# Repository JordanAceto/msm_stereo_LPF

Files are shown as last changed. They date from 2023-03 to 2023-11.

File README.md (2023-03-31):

## Stereo 24dB/octave Lowpass Filter for Matt

### Features:
- All analog audio path
- Minimoog style resonant lowpass filters
- Subtle adjustable compression
- FET based overdrive
- Envelope follower with adjustable attack time
- Dual digital LFO with flexible routing and syncing options
- Sum and Difference outputs for interesting Mono combinations of the two filters

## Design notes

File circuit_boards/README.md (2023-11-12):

## PCB design and documentation files

### The system is made up of several printed circuit boards
- `compression_and_distortion` has an NE570 compressor and FET distortion circuit
- `lowpass_filters` contains the voltage controlled lowpass filters
- `envelope_follower` is an analog envelope follower
- `LFO_and_PS` contains a regulated bipolar DC power supply and digital LFO

### Each circuit board has a subdirectory with
- KiCad 7 project files with KiCad
- Documentation needed to build the board in `docs`

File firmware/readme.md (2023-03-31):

# STM32L031 Dual Low Frequency Oscillator

---

### Features:

- Rate and Depth controls per LFO, all ranging from 0v to +3.3v:
- LFO A has TRIANGLE, SQUARE, and SAMPLE & HOLD waveforms
- LFO B is always TRIANGLE wave
- LFO A can be switched to FAST mode, which pushes the frequency into the audio range for scifi FX

---

### LFO Modes:

A 3-position rotary switch determines how LFO A and LFO B work together.

#### NORM Mode
LFO A and LFO B are completely independent. Below is one example setting, with LFO A in blue set relatively slow and LFO B at a faster rate in purple.

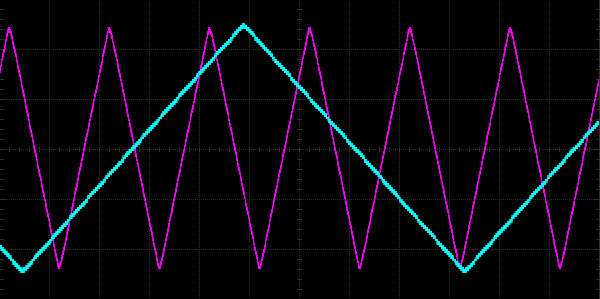
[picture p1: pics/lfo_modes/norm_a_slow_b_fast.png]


#### SYNC TO A Mode
Forces both A and B sides to use only the output of LFO A. The B side may be inverted relative to the A side. 

This mode is good for straightforward stereo panning effects. The RATE B control has no effect in this mode.

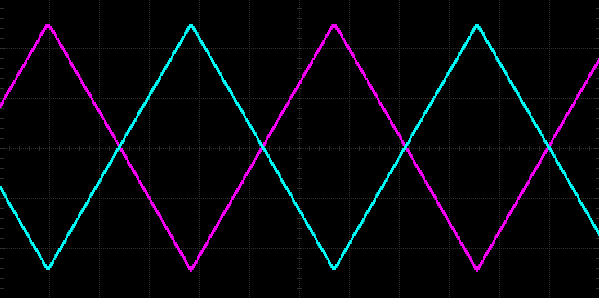
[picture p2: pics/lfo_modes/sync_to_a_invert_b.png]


#### ADD Mode
The most complex. The contributions of LFO A and LFO B are summed together.

In this mode the DEPTH A knob controls how much of LFO A is applied to both filter A and filter B. Likewise the DEPTH B knob controls how much of LFO B is applied to both filters.

The INVERT B switch inverts the contribution of LFO B going to filter B.

This allows us to create a variety of complex modulation schemes like shown below. In all images the contribution going to filter A is shown in blue and filter B modulation is purple.

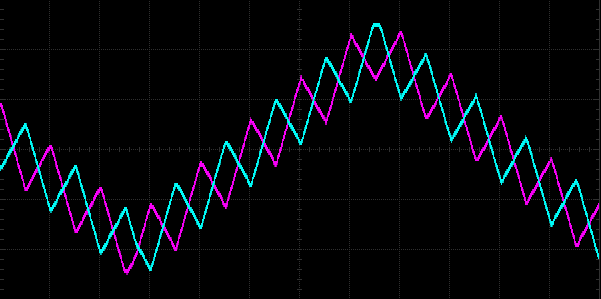
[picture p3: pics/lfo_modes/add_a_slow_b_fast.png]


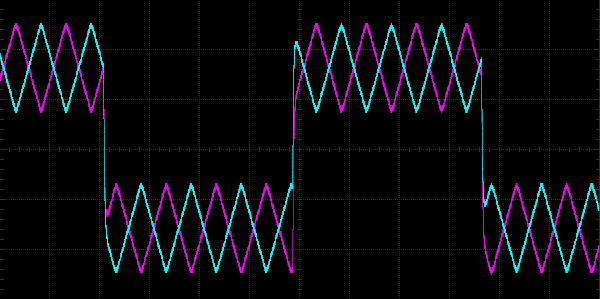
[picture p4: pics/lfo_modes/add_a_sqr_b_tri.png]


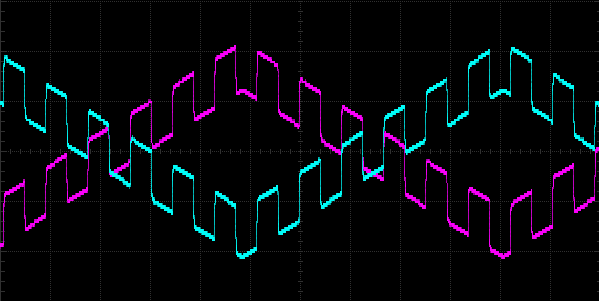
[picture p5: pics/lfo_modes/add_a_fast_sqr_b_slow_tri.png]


---

### Prerequisites for building and flashing the project:
- [arm-none-eabi toolchain](https://developer.arm.com/tools-and-software/open-source-software/developer-tools/gnu-toolchain/gnu-rm/downloads)
- [GNU make](https://www.gnu.org/software/make/)
- [st-link utility](https://www.st.com/en/development-tools/stsw-link004.html)
- A physical st-link device. I use an old [Nucleo board](https://www.st.com/en/evaluation-tools/stm32-nucleo-boards.html).
- If you have a different preferred method of flashing STM32 chips (openocd, etc) then feel free to go wild.

### To build the project:
- `$ make`

### To flash an STM32 chip connected to an st-link programmer via the SWD header:
- `$ make write`

---

### Firmware directory organization:
- `third_party` contains the STM32 supplied CMSIS header-only files, assembly startup routine, and linker script.
- `BSP` is a very basic "Board Support Package", this module initializes and modifies the various stm32 peripherals used by the system.
- `lib` contains user library files.
- `src` contains the main application files.
- `utils` contains non-c language utility source files such as a python lookup table generating script.
- `bin` is the destination for output files generated by the build process.

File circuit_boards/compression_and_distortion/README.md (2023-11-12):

# compression_and_distortion

## compressor_distortion

PCB front
PCB back

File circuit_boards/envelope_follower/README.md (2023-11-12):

# envelope_follower

## envelope_follower

PCB front
PCB back

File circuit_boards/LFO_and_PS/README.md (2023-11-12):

# LFO_and_PS

## lfo_and_power_supply

PCB front
PCB back

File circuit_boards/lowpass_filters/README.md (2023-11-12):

# lowpass_filters

## filter_board

PCB front
PCB back

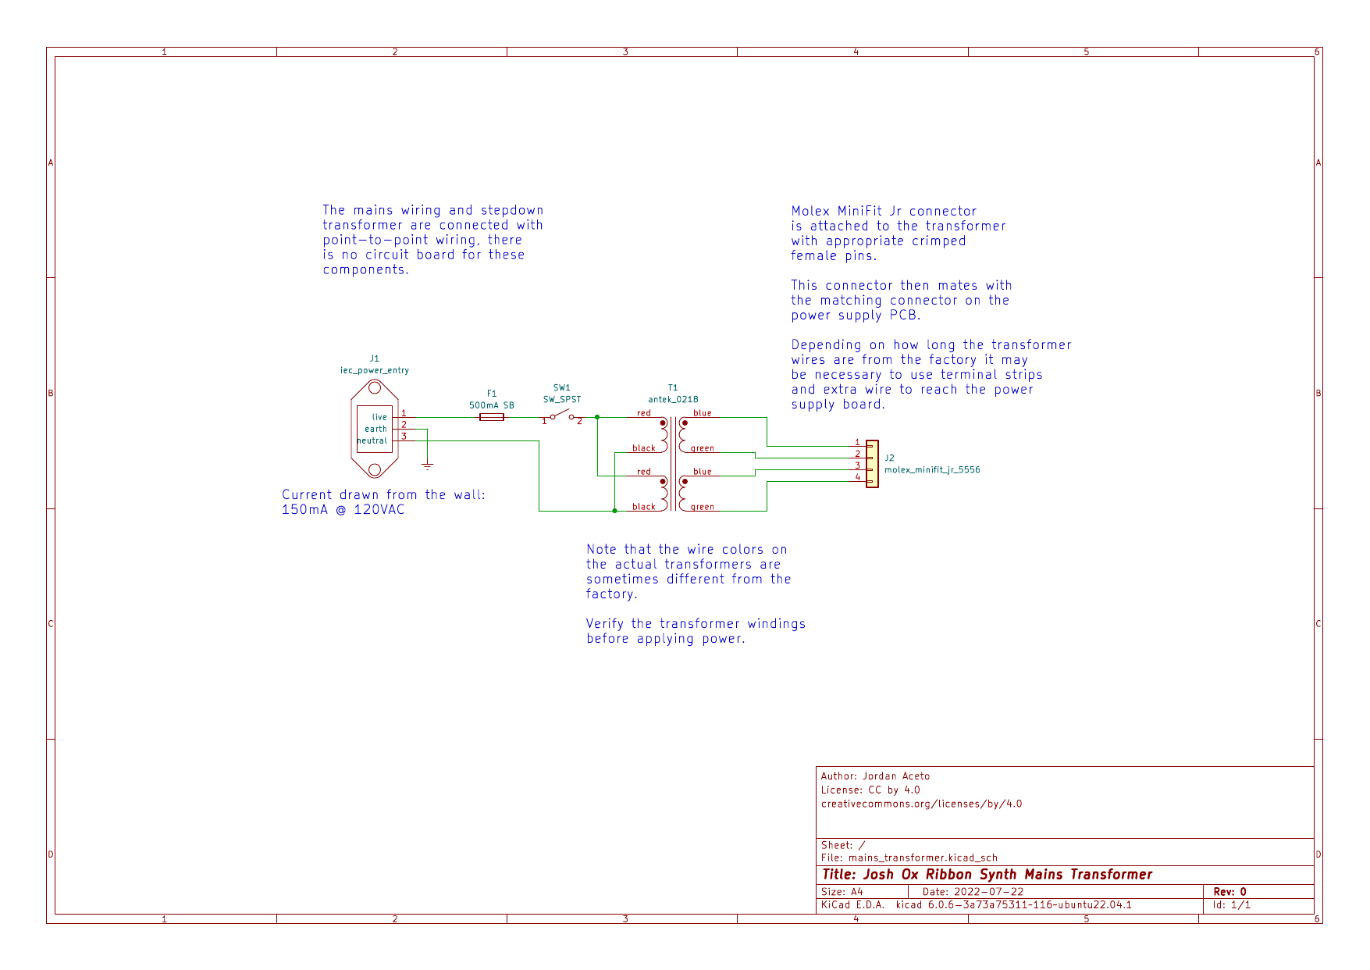
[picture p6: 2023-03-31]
circuit_boards/mains_transformer/main_transformer.png

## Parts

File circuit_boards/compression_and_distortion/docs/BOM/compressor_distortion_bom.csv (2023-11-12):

# | Reference | Qty | Value | Footprint | DNP
1 | C1, C2, C3, C4, C8, C9, C10, C11, C21, C22, C23, C24 | 12 | 1u | Capacitor_THT:C_Rect_L7.2mm_W5.5mm_P5.00mm_FKS2_FKP2_MKS2_MKP2
2 | C5, C12 | 2 | 2u2 | Capacitor_THT:CP_Radial_D6.3mm_P2.50mm
3 | C6, C13, C16, C19, C27, C28 | 6 | 10u | Capacitor_THT:CP_Radial_D6.3mm_P2.50mm
4 | C7, C14 | 2 | 220p | Capacitor_SMD:C_0805_2012Metric
5 | C15, C17, C18, C20 | 4 | 100n | Capacitor_THT:C_Rect_L7.2mm_W2.5mm_P5.00mm_FKS2_FKP2_MKS2_MKP2
6 | C25, C26 | 2 | 100p | Capacitor_SMD:C_0805_2012Metric
7 | C29, C30, C31, C32, C33, C34, C35, C36, C37, C38, C39 | 11 | 100n | Capacitor_SMD:C_0805_2012Metric
8 | D1, D2 | 2 | red | LED_SMD:LED_0805_2012Metric
9 | D3, D4 | 2 | red_green | LED_THT:LED_D5.0mm
10 | J1 | 1 | dry_in | Connector_Molex:Molex_KK-254_AE-6410-04A_1x04_P2.54mm_Vertical
11 | J2 | 1 | vcf_board_send_receive | Connector_Molex:Molex_KK-254_AE-6410-08A_1x08_P2.54mm_Vertical
12 | J3 | 1 | final_out | Connector_Molex:Molex_KK-254_AE-6410-07A_1x07_P2.54mm_Vertical
13 | J4 | 1 | power_entry | Connector_IDC:IDC-Header_2x05_P2.54mm_Vertical
14 | Q1, Q3 | 2 | BS170 | Package_TO_SOT_THT:TO-92_Wide
15 | Q2, Q4 | 2 | BF245A | Package_TO_SOT_THT:TO-92_Wide
16 | R1, R2 | 2 | 470k | Resistor_SMD:R_0805_2012Metric
17 | R3, R9, R20, R28 | 4 | 10k | Resistor_SMD:R_0805_2012Metric
18 | R4, R10 | 2 | 3k3 | Resistor_SMD:R_0805_2012Metric
19 | R5, R6, R11, R12 | 4 | 47k | Resistor_SMD:R_0805_2012Metric
20 | R7, R13 | 2 | 2M2 | Resistor_SMD:R_0805_2012Metric
21 | R8, R14 | 2 | 22k | Resistor_SMD:R_0805_2012Metric
22 | R15, R21, R23, R29 | 4 | 1k | Resistor_SMD:R_0805_2012Metric
23 | R16, R17, R24, R25 | 4 | 1M | Resistor_SMD:R_0805_2012Metric
24 | R18, R26 | 2 | 4k7 | Resistor_SMD:R_0805_2012Metric
25 | R19, R27 | 2 | 2k | Resistor_SMD:R_0805_2012Metric
26 | R22, R30, R31, R32, R33, R34, R35, R36, R37, R38, R39, R40, R41, R42, R43 | 15 | 100k | Resistor_SMD:R_0805_2012Metric
27 | R44, R45 | 2 | 100 | Resistor_SMD:R_0805_2012Metric
28 | RV1, RV2, RV3 | 3 | 100k | Potentiometer_THT:Potentiometer_Alpha_RD902F-40-00D_Dual_Vertical
29 | RV4, RV5 | 2 | 50k | Potentiometer_THT:Potentiometer_Bourns_3296W_Vertical
30 | SW1 | 1 | bypass_switch_A | custom_footprints:DPDT_mini_toggle
31 | SW2 | 1 | bypass_switch_B | custom_footprints:DPDT_mini_toggle
32 | TP1 | 1 | compressor_A | TestPoint:TestPoint_Keystone_5000-5004_Miniature
33 | TP2 | 1 | compressor_B | TestPoint:TestPoint_Keystone_5000-5004_Miniature
34 | TP3 | 1 | distortion_A | TestPoint:TestPoint_Keystone_5000-5004_Miniature
35 | TP4 | 1 | distortion_B | TestPoint:TestPoint_Keystone_5000-5004_Miniature
36 | U1, U3, U4, U5, U6 | 5 | TL072 | Package_SO:SOIC-8_3.9x4.9mm_P1.27mm
37 | U2 | 1 | NE570 | Package_DIP:DIP-16_W7.62mm_Socket

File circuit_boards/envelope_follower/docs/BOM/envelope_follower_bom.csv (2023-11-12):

# | Reference | Qty | Value | Footprint | DNP
1 | C1 | 1 | 470n | Capacitor_THT:C_Rect_L7.0mm_W3.5mm_P5.00mm
2 | C2 | 1 | 220n | Capacitor_THT:C_Rect_L7.0mm_W3.5mm_P5.00mm
3 | C3 | 1 | 2u2 | Capacitor_THT:CP_Radial_D6.3mm_P2.50mm
4 | C4, C5 | 2 | 10u | Capacitor_THT:CP_Radial_D6.3mm_P2.50mm
5 | C6, C7, C8, C9, C10, C11 | 6 | 100n | Capacitor_SMD:C_0805_2012Metric
6 | D1, D2, D3, D4, D5, D6 | 6 | 1N4148W | Diode_SMD:D_SOD-123
7 | D7 | 1 | red_green | LED_THT:LED_D5.0mm
8 | J1 | 1 | audio_IO | Connector_Molex:Molex_KK-254_AE-6410-03A_1x03_P2.54mm_Vertical
9 | J2 | 1 | vcf_board_port | Connector_Molex:Molex_KK-254_AE-6410-04A_1x04_P2.54mm_Vertical
10 | J3 | 1 | power_entry | Connector_IDC:IDC-Header_2x05_P2.54mm_Vertical
11 | R1, R7 | 2 | 5k6 | Resistor_SMD:R_0805_2012Metric
12 | R2, R3, R4, R5, R6, R14, R15, R16, R17 | 9 | 100k | Resistor_SMD:R_0805_2012Metric
13 | R8, R9 | 2 | 10k | Resistor_SMD:R_0805_2012Metric
14 | R10 | 1 | 1k | Resistor_SMD:R_0805_2012Metric
15 | R11 | 1 | 680k | Resistor_SMD:R_0805_2012Metric
16 | R12 | 1 | 220k | Resistor_SMD:R_0805_2012Metric
17 | R13 | 1 | 47k | Resistor_SMD:R_0805_2012Metric
18 | R18 | 1 | 3k3 | Resistor_SMD:R_0805_2012Metric
19 | RV1, RV2 | 2 | 100k | Potentiometer_THT:Potentiometer_Alpha_RD901F-40-00D_Single_Vertical
20 | RV3, RV4 | 2 | 100k C.D. | Potentiometer_THT:Potentiometer_Alpha_RD901F-40-00D_Single_Vertical
21 | TP1 | 1 | dry_audio | TestPoint:TestPoint_Keystone_5000-5004_Miniature
22 | TP2 | 1 | fwr_positive_signal | TestPoint:TestPoint_Keystone_5000-5004_Miniature
23 | TP3 | 1 | raw_env | TestPoint:TestPoint_Keystone_5000-5004_Miniature
24 | TP4 | 1 | env_A | TestPoint:TestPoint_Keystone_5000-5004_Miniature
25 | TP5 | 1 | env_B | TestPoint:TestPoint_Keystone_5000-5004_Miniature
26 | U1, U2, U3 | 3 | TL072 | Package_SO:SOIC-8_3.9x4.9mm_P1.27mm

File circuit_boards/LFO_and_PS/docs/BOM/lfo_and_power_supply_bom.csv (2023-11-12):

# | Reference | Qty | Value | Footprint | DNP
1 | C1, C2 | 2 | 470n | Capacitor_SMD:C_0805_2012Metric
2 | C3, C4, C5, C8, C9, C11, C12, C15, C16, C19, C21, C22, C24, C25, C27, C28 | 16 | 100n | Capacitor_SMD:C_0805_2012Metric
3 | C6, C7, C20 | 3 | 1u | Capacitor_SMD:C_0805_2012Metric
4 | C10, C14 | 2 | 3300u | Capacitor_THT:CP_Radial_D18.0mm_P7.50mm
5 | C13, C17 | 2 | 10u | Capacitor_THT:CP_Radial_D6.3mm_P2.50mm
6 | C18 | 1 | 2u2 | Capacitor_THT:CP_Radial_D6.3mm_P2.50mm
7 | C23, C26 | 2 | 10u | Capacitor_SMD:C_0805_2012Metric
8 | D1, D2, D3, D4, D5, D6, D7, D8 | 8 | 1N4002 | Diode_THT:D_DO-41_SOD81_P10.16mm_Horizontal
9 | FB1, FB2 | 2 | 100R @ 100MHz | Inductor_SMD:L_0805_2012Metric
10 | J1 | 1 | AC_power_in | Connector_Molex:Molex_Mini-Fit_Jr_5566-04A_2x02_P4.20mm_Vertical
11 | J2, J3, J4, J5 | 4 | power_out | Connector_IDC:IDC-Header_2x05_P2.54mm_Vertical
12 | J6 | 1 | filter_board_port | Connector_Molex:Molex_KK-254_AE-6410-03A_1x03_P2.54mm_Vertical
13 | J7 | 1 | rate_pot | Connector_Molex:Molex_KK-254_AE-6410-05A_1x05_P2.54mm_Vertical
14 | J8 | 1 | swd_header | Connector_PinHeader_2.54mm:PinHeader_1x04_P2.54mm_Vertical
15 | R1, R4 | 2 | 100k | Resistor_SMD:R_0805_2012Metric
16 | R2, R5 | 2 | 33k | Resistor_SMD:R_0805_2012Metric
17 | R3, R6 | 2 | 6k8 | Resistor_SMD:R_0805_2012Metric
18 | R7, R10, R11 | 3 | 10k | Resistor_SMD:R_0805_2012Metric
19 | R8 | 1 | DNF | Resistor_SMD:R_0805_2012Metric
20 | R9 | 1 | 15k | Resistor_SMD:R_0805_2012Metric
21 | R12, R13 | 2 | 240 | Resistor_SMD:R_0805_2012Metric
22 | RV1, RV2, RV3 | 3 | 10k | Potentiometer_THT:Potentiometer_Alpha_RD901F-40-00D_Single_Vertical
23 | RV5, RV6 | 2 | 5k | Potentiometer_THT:Potentiometer_Bourns_3296W_Vertical
24 | SW1 | 1 | SW_SPDT_center_off | custom_footprints:SPDT_mini_toggle
25 | SW2 | 1 | SR1712F-0203 | custom_footprints:SR1712F_rotary_switch
26 | SW3 | 1 | SW_SPDT | custom_footprints:SPDT_mini_toggle
27 | TP1 | 1 | LFO_A | TestPoint:TestPoint_Keystone_5000-5004_Miniature
28 | TP2 | 1 | LFO_B | TestPoint:TestPoint_Keystone_5000-5004_Miniature
29 | TP3 | 1 | V+ | TestPoint:TestPoint_Keystone_5000-5004_Miniature
30 | TP4 | 1 | 3v3 | TestPoint:TestPoint_Keystone_5000-5004_Miniature
31 | TP5 | 1 | GND | TestPoint:TestPoint_Bridge_Pitch7.62mm_Drill1.3mm
32 | TP6 | 1 | V- | TestPoint:TestPoint_Keystone_5000-5004_Miniature
33 | U1 | 1 | TL072 | Package_SO:SOIC-8_3.9x4.9mm_P1.27mm
34 | U2 | 1 | STM32L031F4Px | Package_SO:TSSOP-20_4.4x6.5mm_P0.65mm
35 | U3 | 1 | MCP4822 | Package_SO:TSSOP-8_3x3mm_P0.65mm
36 | U4 | 1 | LM317_TO-220 | Package_TO_SOT_THT:TO-220F-3_Horizontal_TabDown
37 | U5 | 1 | L78L33_SOT89 | Package_TO_SOT_SMD:SOT-89-3
38 | U6 | 1 | LM337_TO220 | Package_TO_SOT_THT:TO-220F-3_Horizontal_TabDown

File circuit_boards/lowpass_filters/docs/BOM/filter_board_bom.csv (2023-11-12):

# | Reference | Qty | Value | Footprint | DNP
1 | C1, C2, C3, C4, C46, C47, C50, C51 | 8 | 1n2 | Capacitor_SMD:C_0805_2012Metric
2 | C5, C13, C14, C17, C25, C26, C29, C30 | 8 | 10u | Capacitor_THT:CP_Radial_D6.3mm_P2.50mm
3 | C6, C8, C18, C20 | 4 | 470n | Capacitor_THT:C_Rect_L7.0mm_W3.5mm_P5.00mm
4 | C7, C10, C11, C12, C19, C22, C23, C24 | 8 | 22n 2.5% | Capacitor_THT:C_Rect_L7.2mm_W7.2mm_P5.00mm_FKS2_FKP2_MKS2_MKP2
5 | C15, C27 | 2 | 220u | Capacitor_THT:CP_Radial_D6.3mm_P2.50mm
6 | C16, C28, C48, C52 | 4 | 100p | Capacitor_SMD:C_0805_2012Metric
7 | C31, C32, C33, C34, C35, C36, C37, C38, C39, C40, C41, C42, C43, C44 | 14 | 100n | Capacitor_SMD:C_0805_2012Metric
8 | C45, C49 | 2 | 100p | Capacitor_SMD:C_0805_2012Metric | DNP
9 | J1 | 1 | comp_dist_board_port | Connector_Molex:Molex_KK-254_AE-6410-08A_1x08_P2.54mm_Vertical
10 | J2 | 1 | ext_cv_port | Connector_Molex:Molex_KK-254_AE-6410-05A_1x05_P2.54mm_Vertical
11 | J3 | 1 | env_board_port | Connector_Molex:Molex_KK-254_AE-6410-04A_1x04_P2.54mm_Vertical
12 | J4 | 1 | lfo_board_port | Connector_Molex:Molex_KK-254_AE-6410-03A_1x03_P2.54mm_Vertical
13 | J5 | 1 | power_entry | Connector_IDC:IDC-Header_2x05_P2.54mm_Vertical
14 | Q1, Q2, Q3, Q4, Q5, Q6, Q7, Q10, Q11, Q12, Q13, Q14, Q15, Q16 | 14 | BCM847 | custom_footprints:SOT457
15 | Q8, Q17 | 2 | MMBT3906 | Package_TO_SOT_SMD:SOT-23
16 | Q9, Q18 | 2 | MMBT3904 | Package_TO_SOT_SMD:SOT-23
17 | R1, R10, R69, R77 | 4 | 330k | Resistor_SMD:R_0805_2012Metric
18 | R2, R11, R71, R79 | 4 | 680k | Resistor_SMD:R_0805_2012Metric
19 | R3, R4, R5, R7, R8, R12, R13, R14, R16, R17, R24, R38, R47, R61 | 14 | 100k | Resistor_SMD:R_0805_2012Metric
20 | R6, R15 | 2 | 3k9 | Resistor_SMD:R_0805_2012Metric
21 | R9, R18 | 2 | Rt | Resistor_SMD:R_0805_2012Metric
22 | R19, R36, R39, R42, R59, R62, R68, R70, R76, R78 | 10 | 220 | Resistor_SMD:R_0805_2012Metric
23 | R20, R21, R30, R43, R44, R53 | 6 | 1k2 | Resistor_SMD:R_0805_2012Metric
24 | R22, R29, R31, R32, R45, R52, R54, R55 | 8 | 150 | Resistor_SMD:R_0805_2012Metric
25 | R23, R27, R28, R46, R50, R51 | 6 | 270k | Resistor_SMD:R_0805_2012Metric
26 | R25, R26, R48, R49 | 4 | 47k | Resistor_SMD:R_0805_2012Metric
27 | R33, R56, R65, R73 | 4 | 120k | Resistor_SMD:R_0805_2012Metric
28 | R34, R40, R57, R63 | 4 | 470 | Resistor_SMD:R_0805_2012Metric
29 | R35, R58 | 2 | 330 | Resistor_SMD:R_0805_2012Metric
30 | R37, R60 | 2 | 680 | Resistor_SMD:R_0805_2012Metric
31 | R41, R64 | 2 | 1M | Resistor_SMD:R_0805_2012Metric
32 | R66, R67, R74, R75 | 4 | 33k | Resistor_SMD:R_0805_2012Metric
33 | R72, R80 | 2 | 4k7 | Resistor_SMD:R_0805_2012Metric
34 | RV1, RV3, RV4, RV5, RV6 | 5 | 100k | Potentiometer_THT:Potentiometer_Alpha_RD901F-40-00D_Single_Vertical
35 | RV2 | 1 | 100k_C.D. | Potentiometer_THT:Potentiometer_Alpha_RD901F-40-00D_Single_Vertical
36 | RV7, RV8, RV9, RV10, RV11, RV12 | 6 | 10k | Potentiometer_THT:Potentiometer_Bourns_3296W_Vertical
37 | TP1 | 1 | dry_A | TestPoint:TestPoint_Keystone_5000-5004_Miniature
38 | TP2 | 1 | wet_A | TestPoint:TestPoint_Keystone_5000-5004_Miniature
39 | TP3 | 1 | mix_A | TestPoint:TestPoint_Keystone_5000-5004_Miniature
40 | TP4 | 1 | freq_CV_A | TestPoint:TestPoint_Keystone_5000-5004_Miniature
41 | TP5 | 1 | fb_CV_A | TestPoint:TestPoint_Keystone_5000-5004_Miniature
42 | TP6 | 1 | dry_B | TestPoint:TestPoint_Keystone_5000-5004_Miniature
43 | TP7 | 1 | wet_B | TestPoint:TestPoint_Keystone_5000-5004_Miniature
44 | TP8 | 1 | mix_B | TestPoint:TestPoint_Keystone_5000-5004_Miniature
45 | TP9 | 1 | freq_CV_B | TestPoint:TestPoint_Keystone_5000-5004_Miniature
46 | TP10 | 1 | fb_CV_B | TestPoint:TestPoint_Keystone_5000-5004_Miniature
47 | U1, U2, U4, U5, U6, U7 | 6 | TL072 | Package_SO:SOIC-8_3.9x4.9mm_P1.27mm
48 | U3 | 1 | SSI2164 | Package_SO:SO-16_3.9x9.9mm_P1.27mm

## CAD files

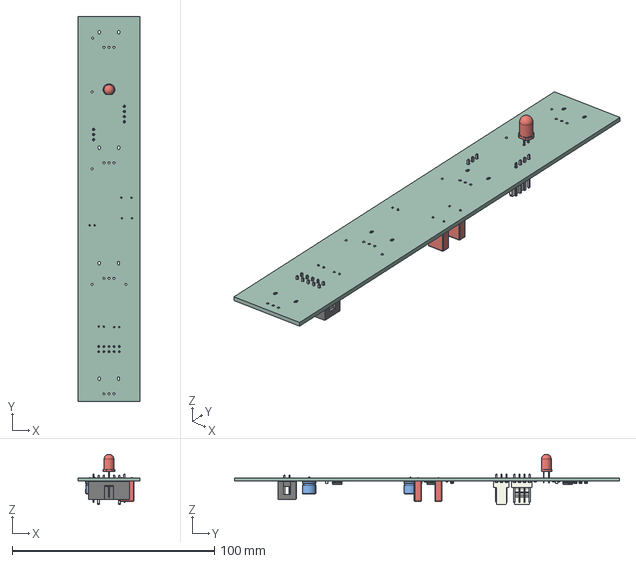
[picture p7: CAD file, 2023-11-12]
circuit_boards/envelope_follower/docs/3D/envelope_follower.step
30.5 x 190.5 x 25.0 mm
envelope_follower PCB

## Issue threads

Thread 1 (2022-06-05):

A and B inputs are swapped on the Compression/Distortion board

JordanAceto, 2022-06-05:
Somehow the A and B inputs are swapped, meaning that when you inject a signal into the A input (pin 1 of J1), the signal goes through the "B" signal path, and vice versa- injecting a signal into J1 pin 4 goes through the "A" signal path.

This is not reflected on the schematic, but it is reflected in the physical circuit board. The schematic and board as ordered early June 2022 do not match.

This can easily be remedied in the physical device by simply swapping the two wires that go to the 1/4" jacks. Connect the A input 1/4" jack to J1 pin 4, and the B input 1/4" jack to J1 pin 1. But if a board revision ever happens this should be corrected.

JordanAceto, 2023-04-15:
Fixed

Closed 2023-04-15.

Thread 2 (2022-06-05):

Envelope Follower LED is off center

JordanAceto, 2022-06-05:
The envelope follower LED is too high on the PCB layout. The hole in the physical panel is a bit lower.

The LED leads can be bent to reach the hole, but if there is ever a pcb revision consider finding the correct LED placement and fixing the layout.

JordanAceto, 2023-04-15:
Won't fix. The one-off panel was made by hand. If anyone makes another one they can drill the hole in the right spot to match the PCB.

Closed 2023-04-15.

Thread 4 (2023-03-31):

Main LEDs are too dim

JordanAceto, 2023-03-31:
The two LEDs which indicate the modulation strength of the filters are too dim.

This can be easily remedied by reducing the value of two resistors on the Compression and Distortion board.
- Change R44 and R45 to 100 ohms. You may go higher than 100 ohms if the LEDs seem too bright.

JordanAceto, 2023-04-15:
Fixed

Closed 2023-04-15.

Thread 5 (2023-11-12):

Envelope follower board, test point TP3 silkscreen on wrong side of PCB

JordanAceto, 2023-11-12:
Not a huge issues, and probably won't be fixed. Just adding it here in case there is a new revision, do fix it in that case.

JordanAceto, 2023-11-12:
Closing as wont-fix, but keeping it here for tracking

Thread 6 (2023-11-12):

Envelope follower attack pot should have a series resistor

JordanAceto, 2023-11-12:
On the envelope follower, a rotary potentiometer wired as a variable resistor sets the attack time. More resistance means longer attack times. This resistance forms the R part of an RC lowpass filter made of RV2 and C3.

When the attack pot is turned fully counter clockwise, the resistance part of the RC is made up of whatever residual wiper impedance the pot has. This will be very low compared to the 100k pot value.

There should be some relatively small resistance in series with RV2, to set the lower bound for the attack time. This is a bit of a trade off:
- We want the RC time constant to be able to get pretty fast for snappy envelopes at the fastest settings
- But when the time constant is very small, lots of ripple gets through the envelope follower, and this can sound weird
- To my taste, a little ripple at the fastest settings can give you a cool "whispy" sound effect, but too much sounds like garbage

Experiment and install a resistor in series with RV2 on the Envelope Follower board that gives a nice feeling range for the attack pot.

JordanAceto, 2023-11-12:
Marking won't fix. It works pretty well in practice. If there is ever a revision, consider adding the resistor described above.

Closed 2023-11-12.

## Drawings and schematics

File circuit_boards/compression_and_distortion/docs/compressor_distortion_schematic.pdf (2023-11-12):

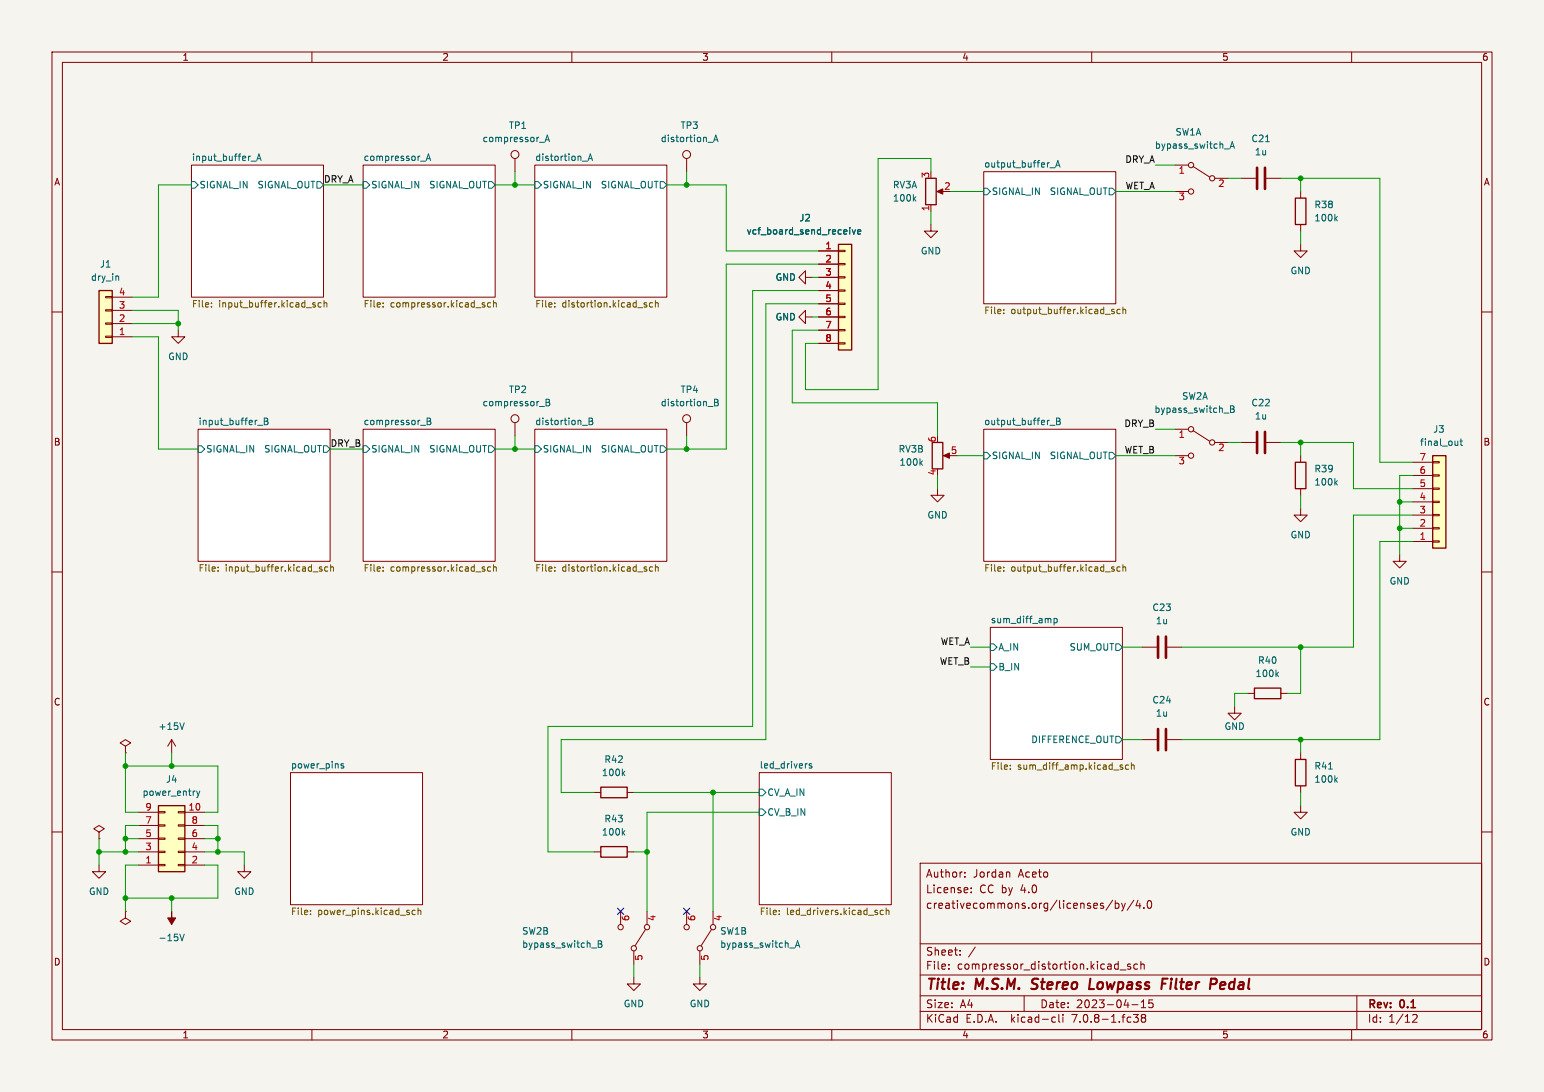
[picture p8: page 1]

Id: 1/12 Title: M.S.M. Stereo Lowpass Filter Pedal File: compressor_distortion.kicad_sch Sheet: / creativecommons.org/licenses/by/4.0

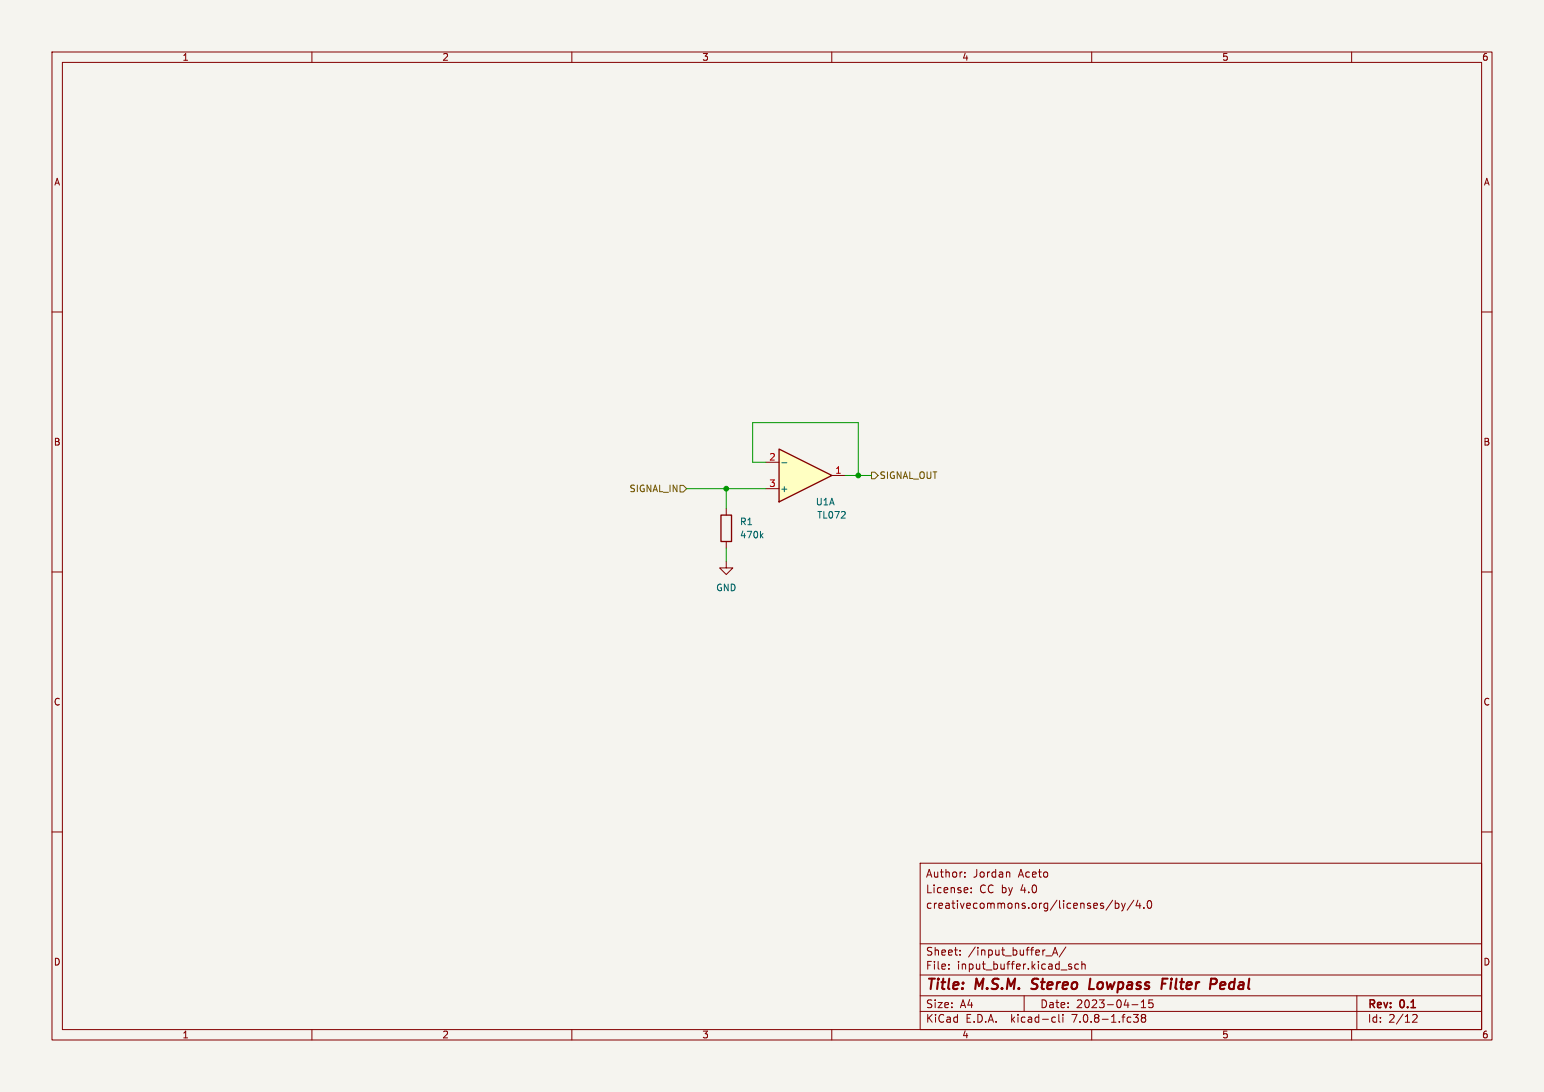
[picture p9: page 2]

creativecommons.org/licenses/by/4.0

Id: 2/12 Title: M.S.M. Stereo Lowpass Filter Pedal File: input_buffer.kicad_sch Sheet: /input_buffer_A/

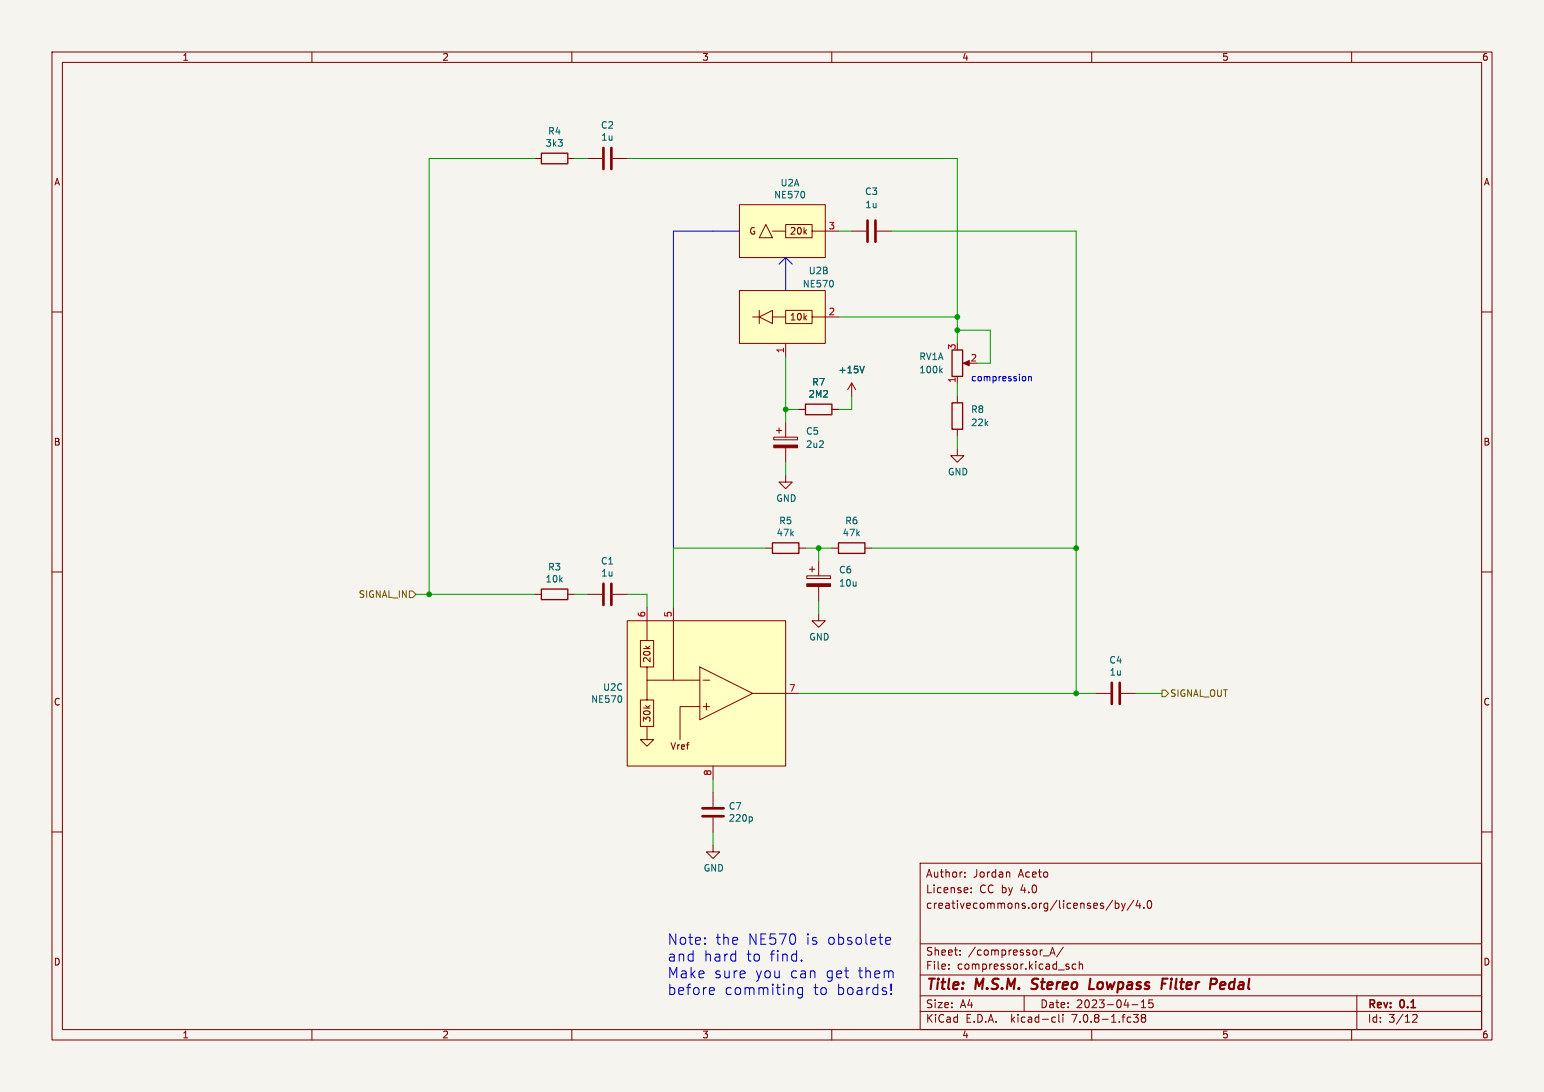
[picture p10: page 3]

creativecommons.org/licenses/by/4.0

Note: the NE570 is obsolete

Id: 3/12 Title: M.S.M. Stereo Lowpass Filter Pedal File: compressor.kicad_sch Sheet: /compressor_A/

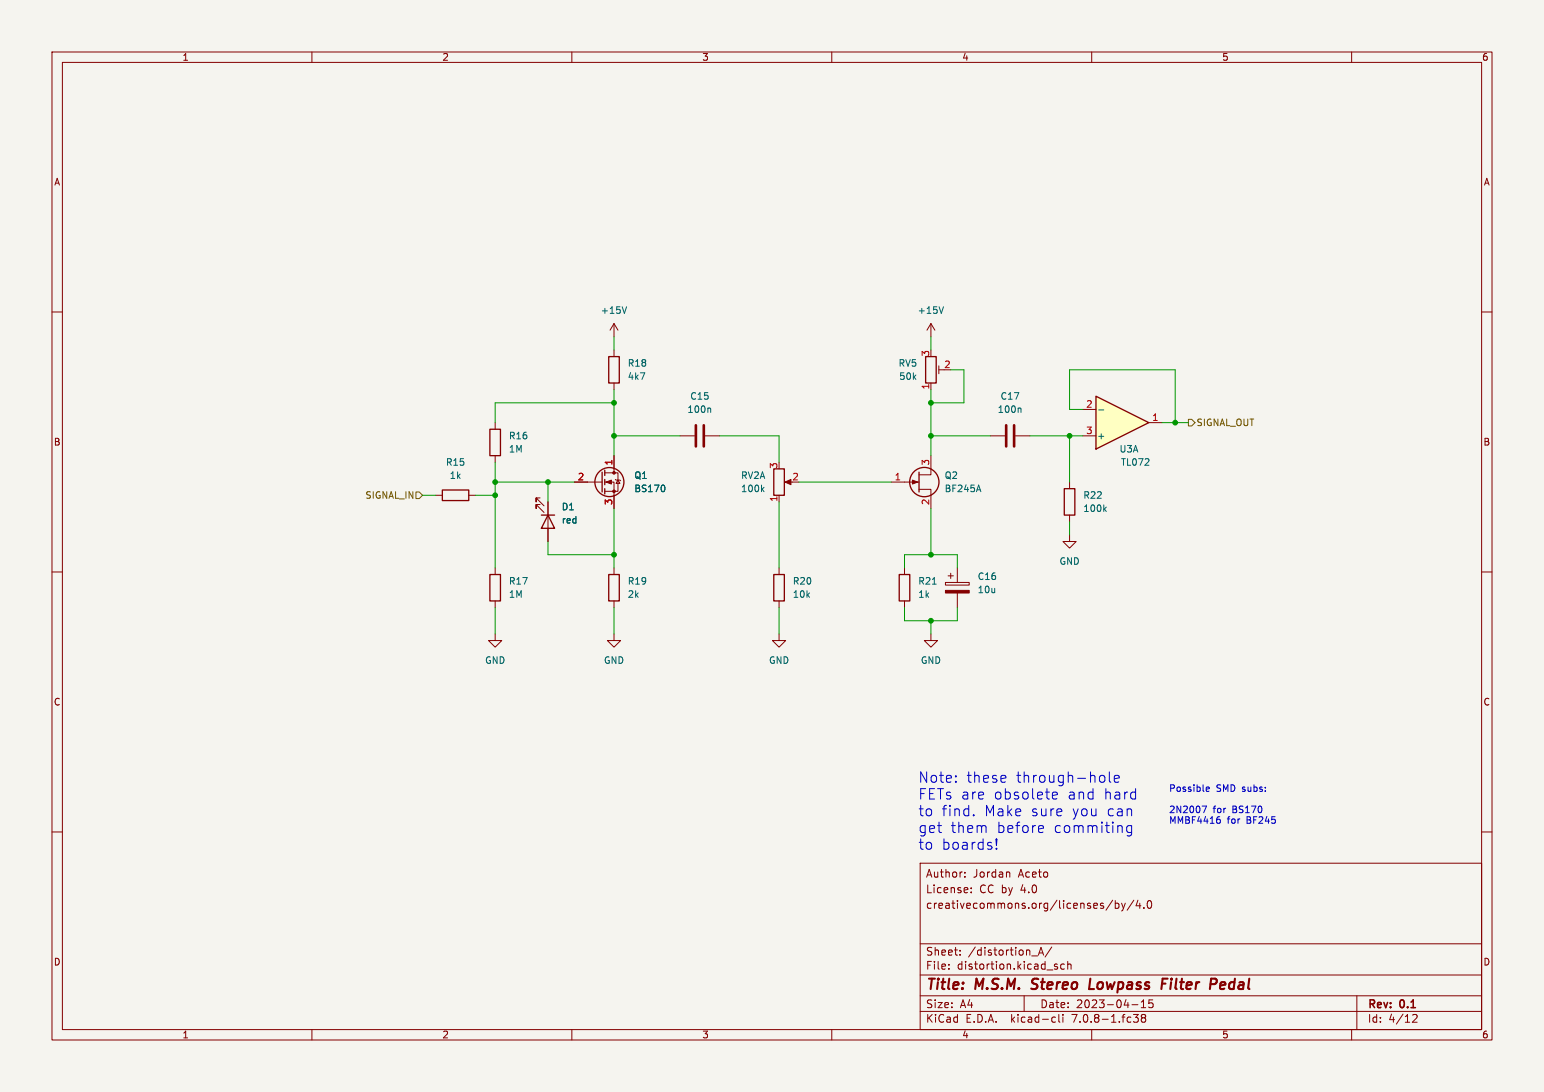
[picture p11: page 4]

Possible SMD subs: 2N2007 for BS170 MMBF4416 for BF245 Note: these through-hole

creativecommons.org/licenses/by/4.0

Id: 4/12 Title: M.S.M. Stereo Lowpass Filter Pedal File: distortion.kicad_sch Sheet: /distortion_A/

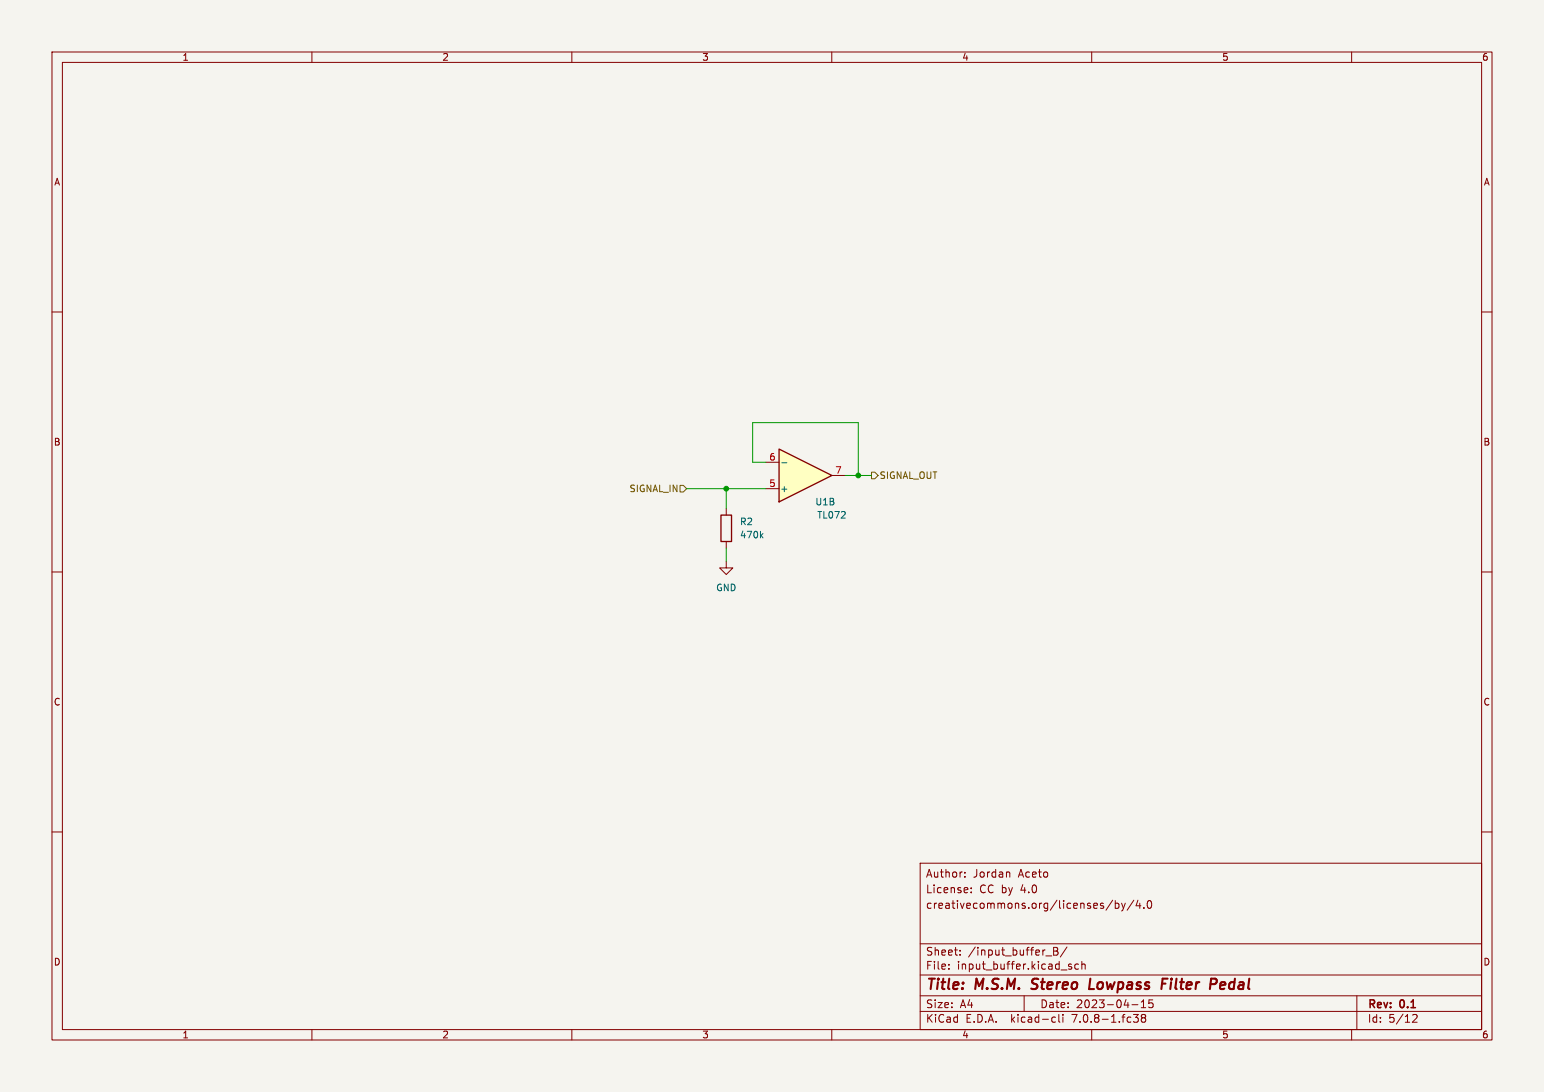
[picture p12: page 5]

creativecommons.org/licenses/by/4.0

Id: 5/12 Title: M.S.M. Stereo Lowpass Filter Pedal File: input_buffer.kicad_sch Sheet: /input_buffer_B/

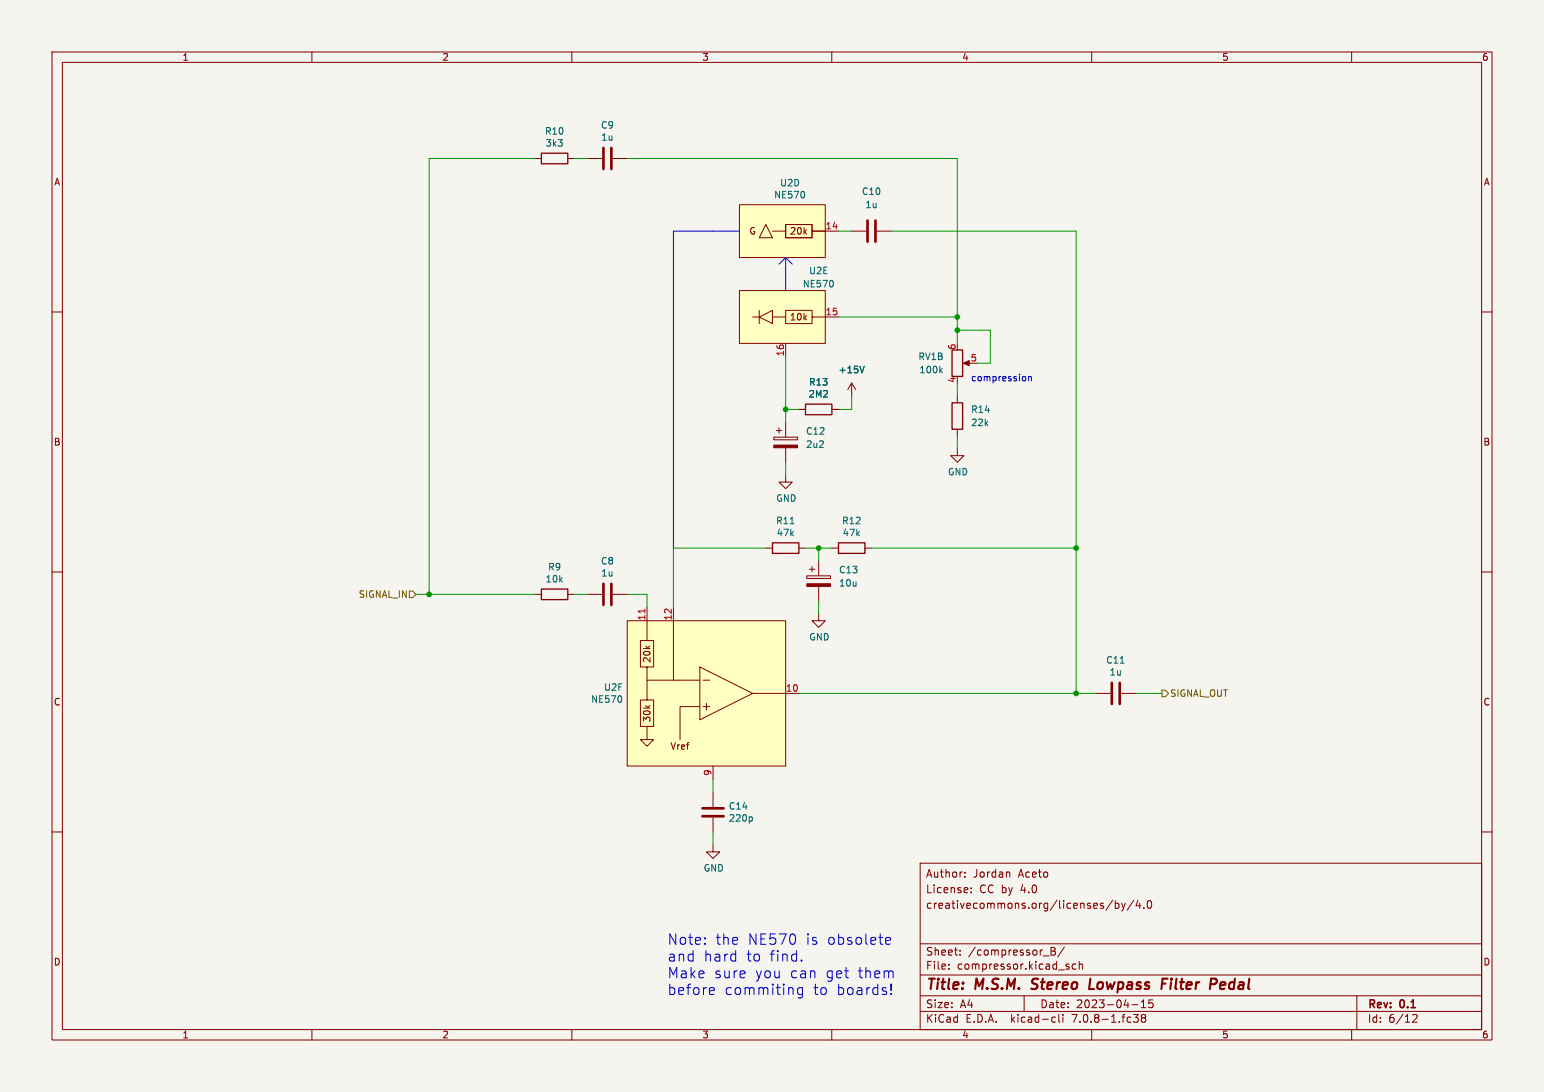
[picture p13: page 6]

creativecommons.org/licenses/by/4.0

Note: the NE570 is obsolete

Id: 6/12 Title: M.S.M. Stereo Lowpass Filter Pedal File: compressor.kicad_sch Sheet: /compressor_B/

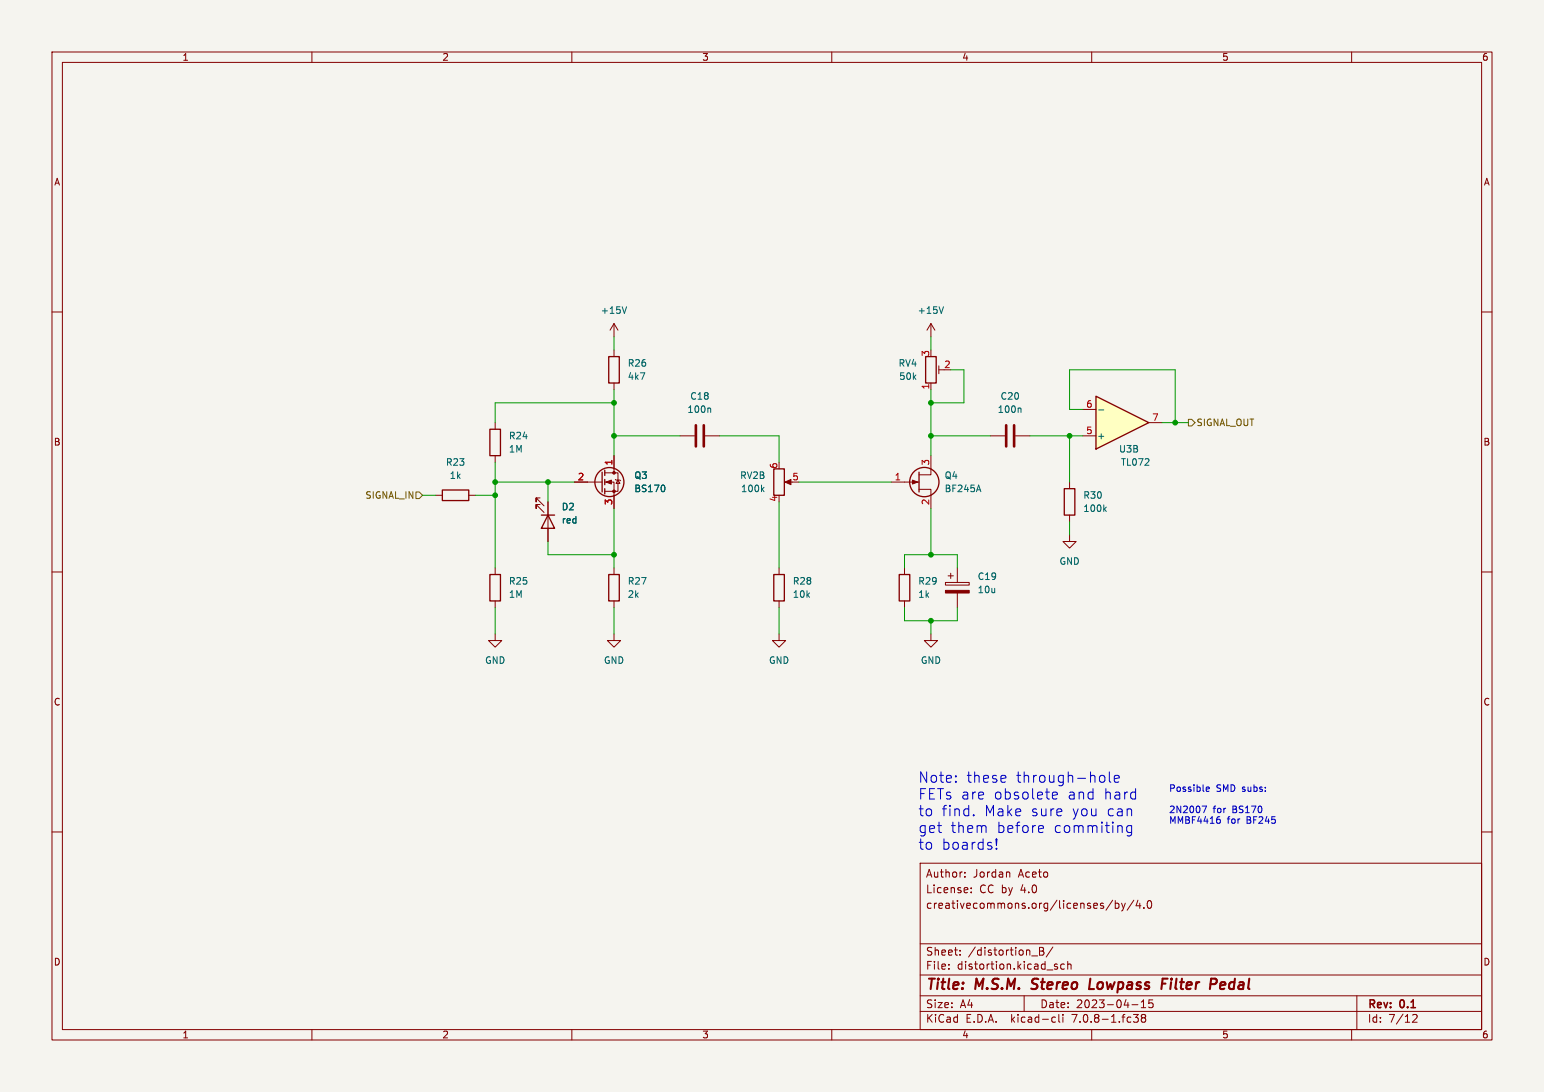
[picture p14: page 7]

Possible SMD subs: 2N2007 for BS170 MMBF4416 for BF245 Note: these through-hole

creativecommons.org/licenses/by/4.0

Id: 7/12 Title: M.S.M. Stereo Lowpass Filter Pedal File: distortion.kicad_sch Sheet: /distortion_B/

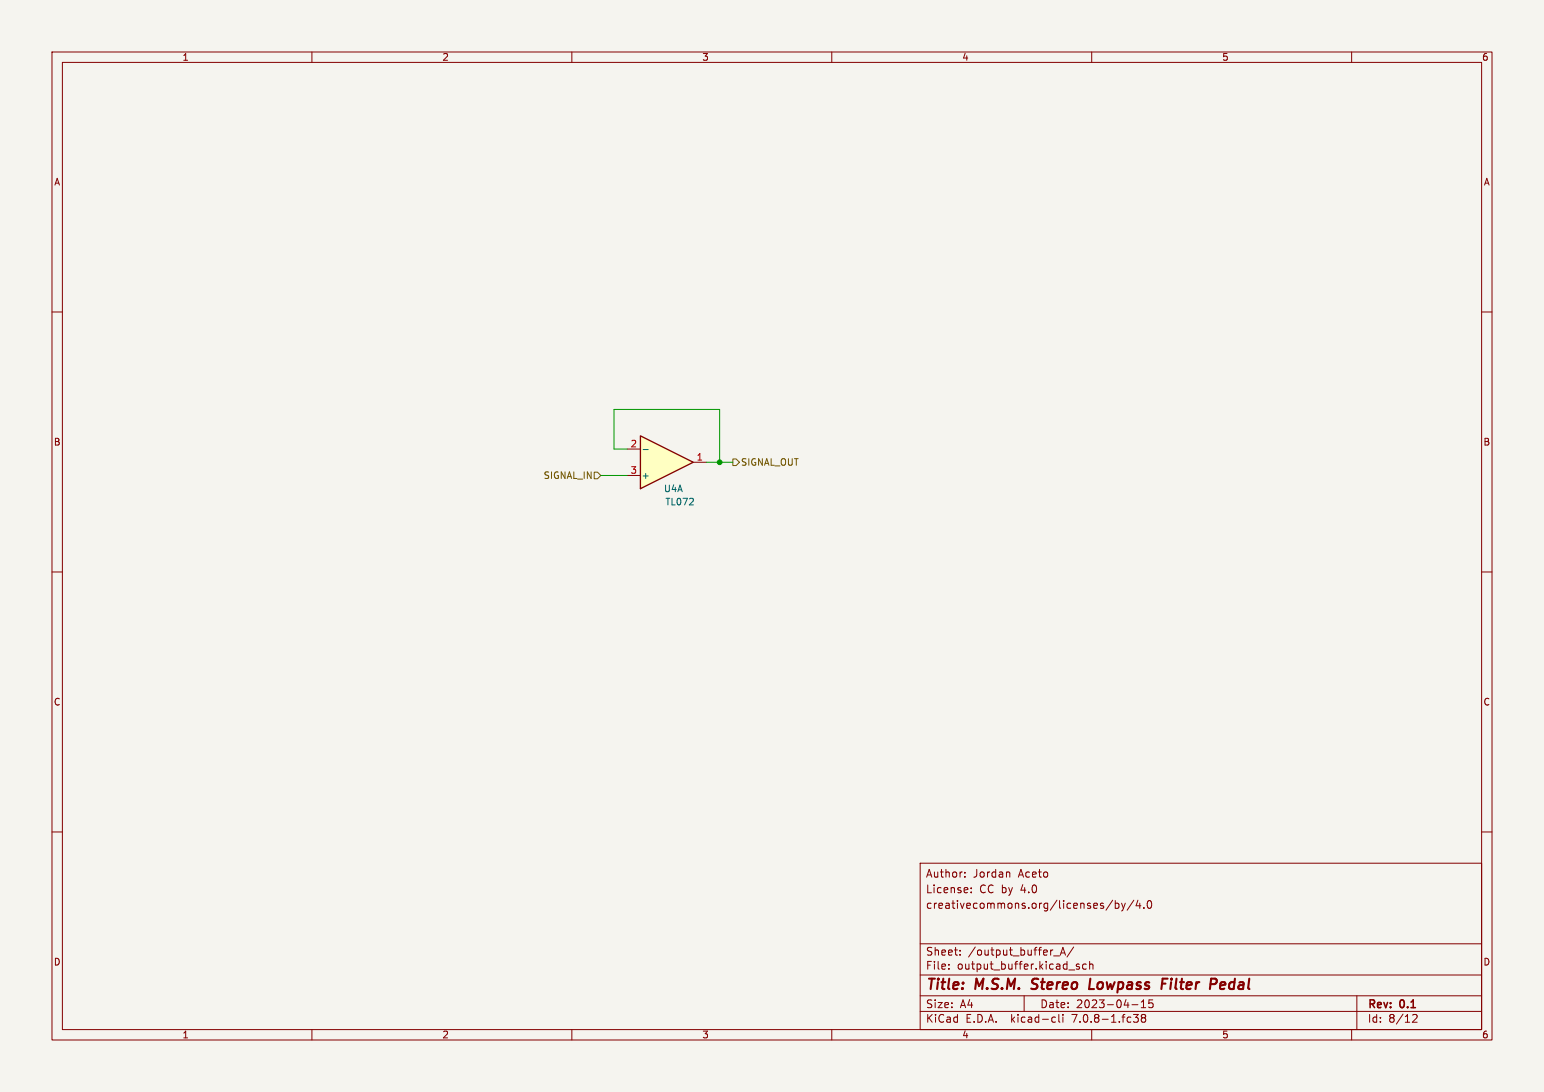
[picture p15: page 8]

creativecommons.org/licenses/by/4.0

Id: 8/12 Title: M.S.M. Stereo Lowpass Filter Pedal File: output_buffer.kicad_sch Sheet: /output_buffer_A/

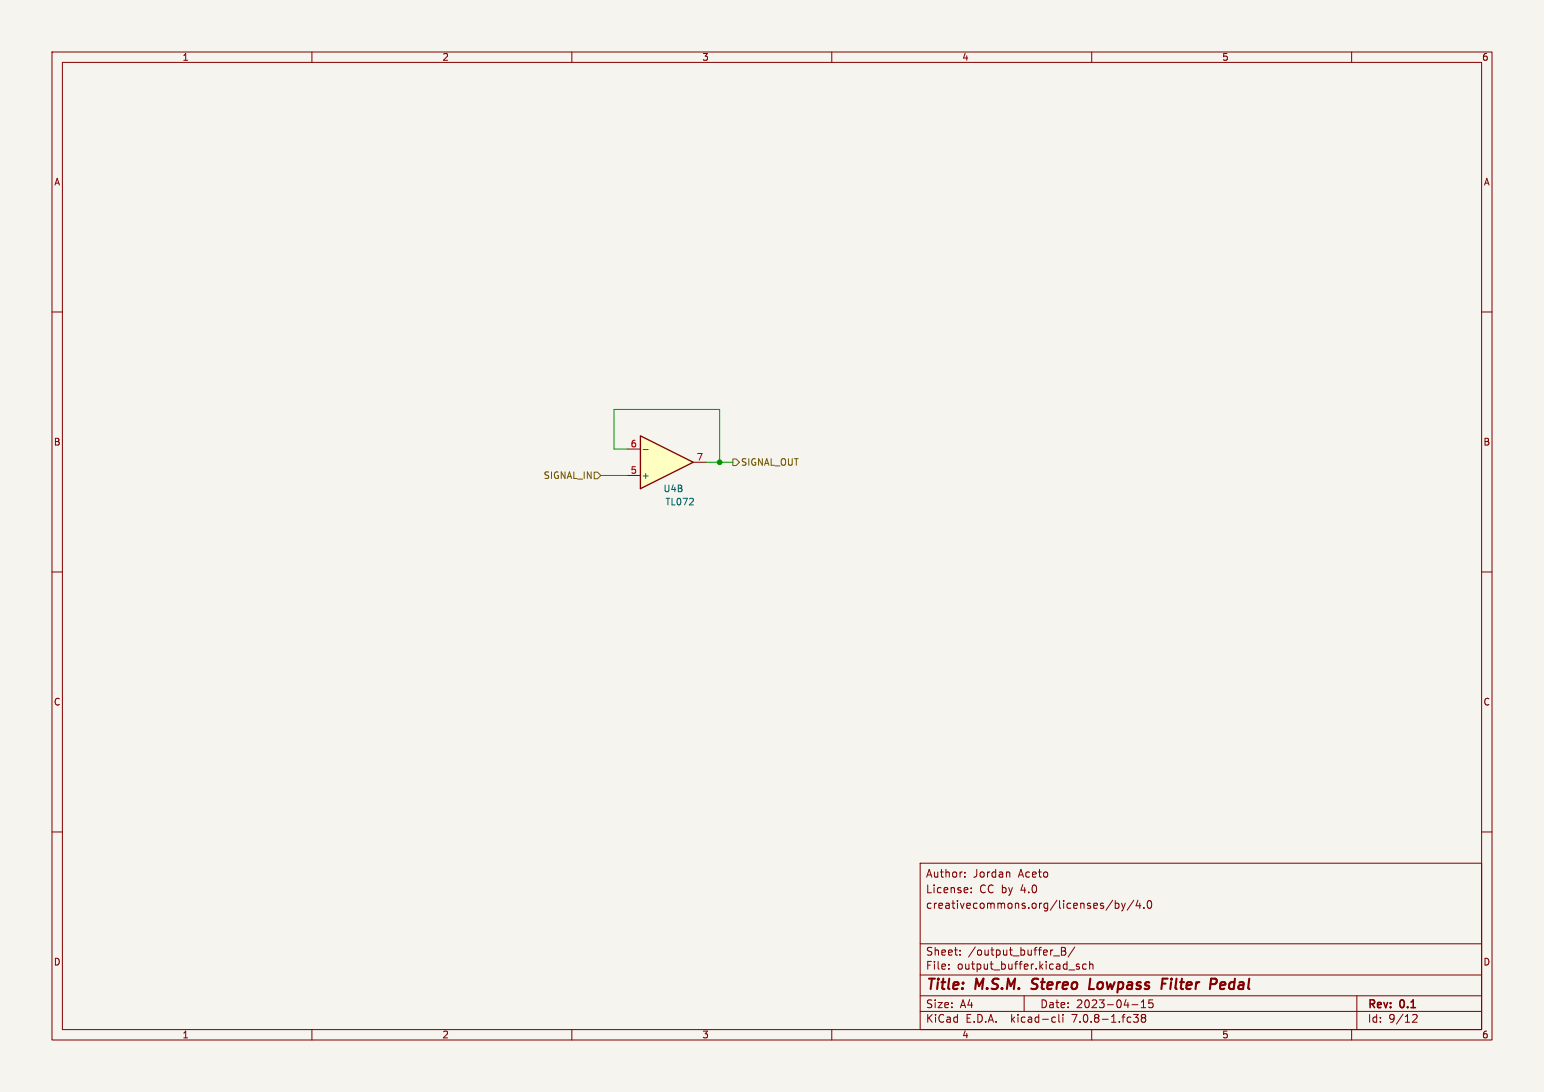
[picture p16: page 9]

creativecommons.org/licenses/by/4.0

Id: 9/12 Title: M.S.M. Stereo Lowpass Filter Pedal File: output_buffer.kicad_sch Sheet: /output_buffer_B/

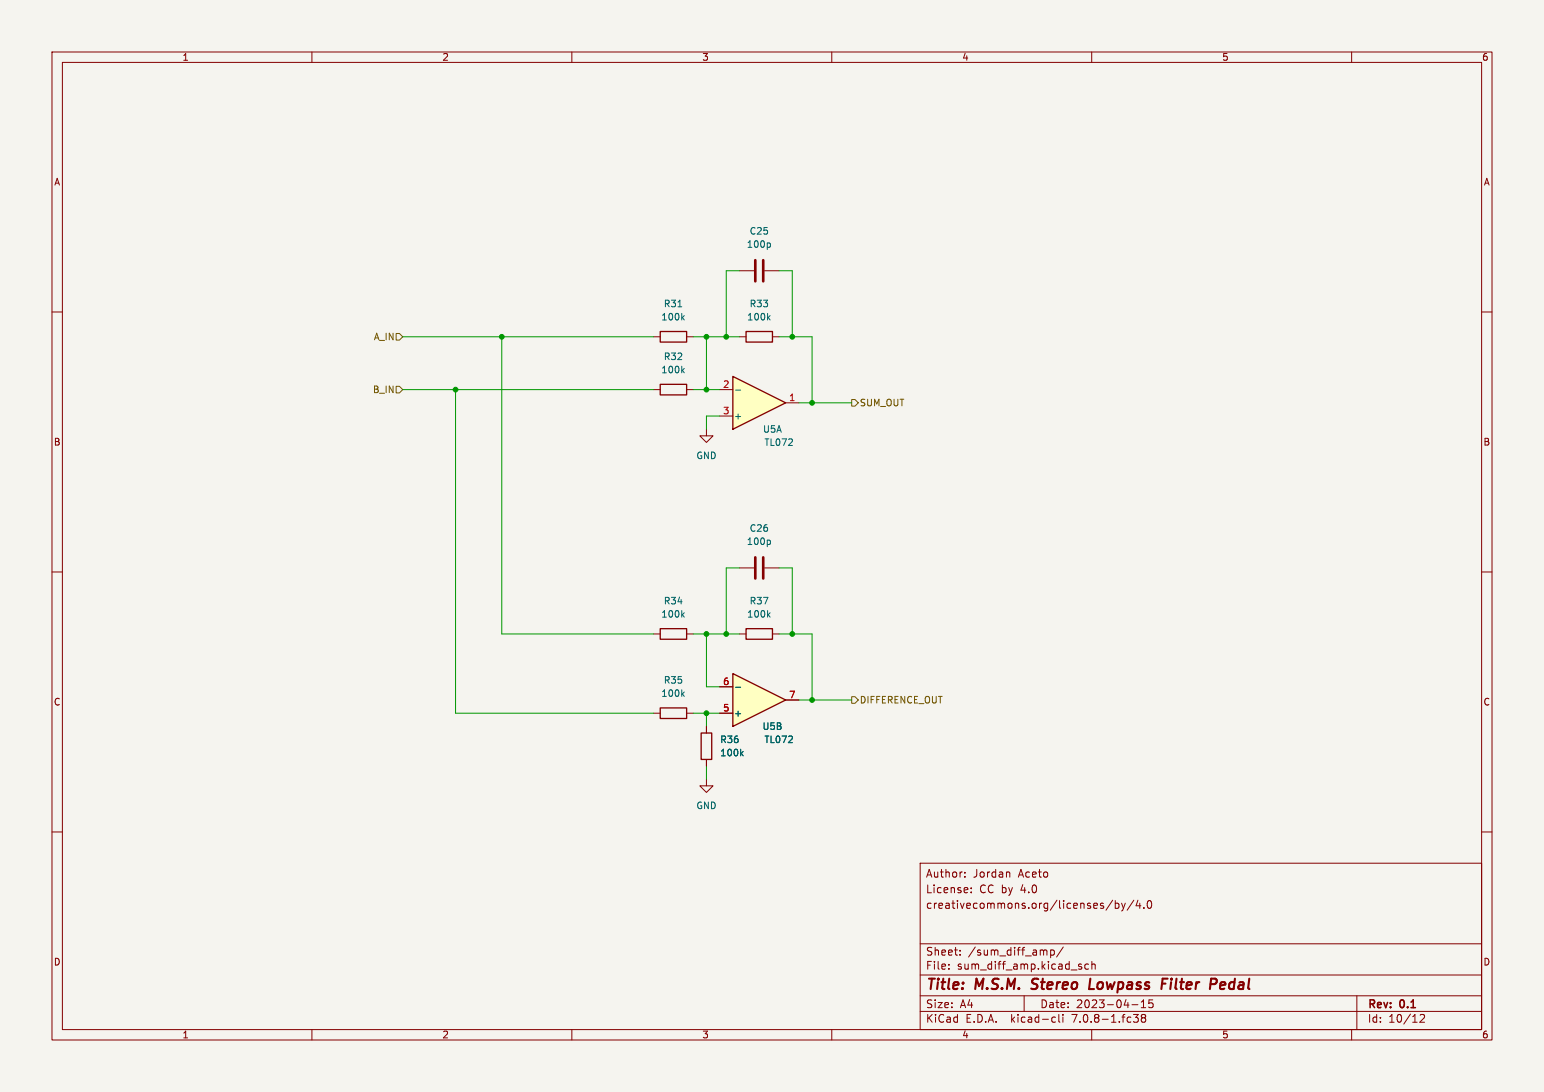
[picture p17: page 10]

creativecommons.org/licenses/by/4.0

Id: 10/12 Title: M.S.M. Stereo Lowpass Filter Pedal File: sum_diff_amp.kicad_sch Sheet: /sum_diff_amp/

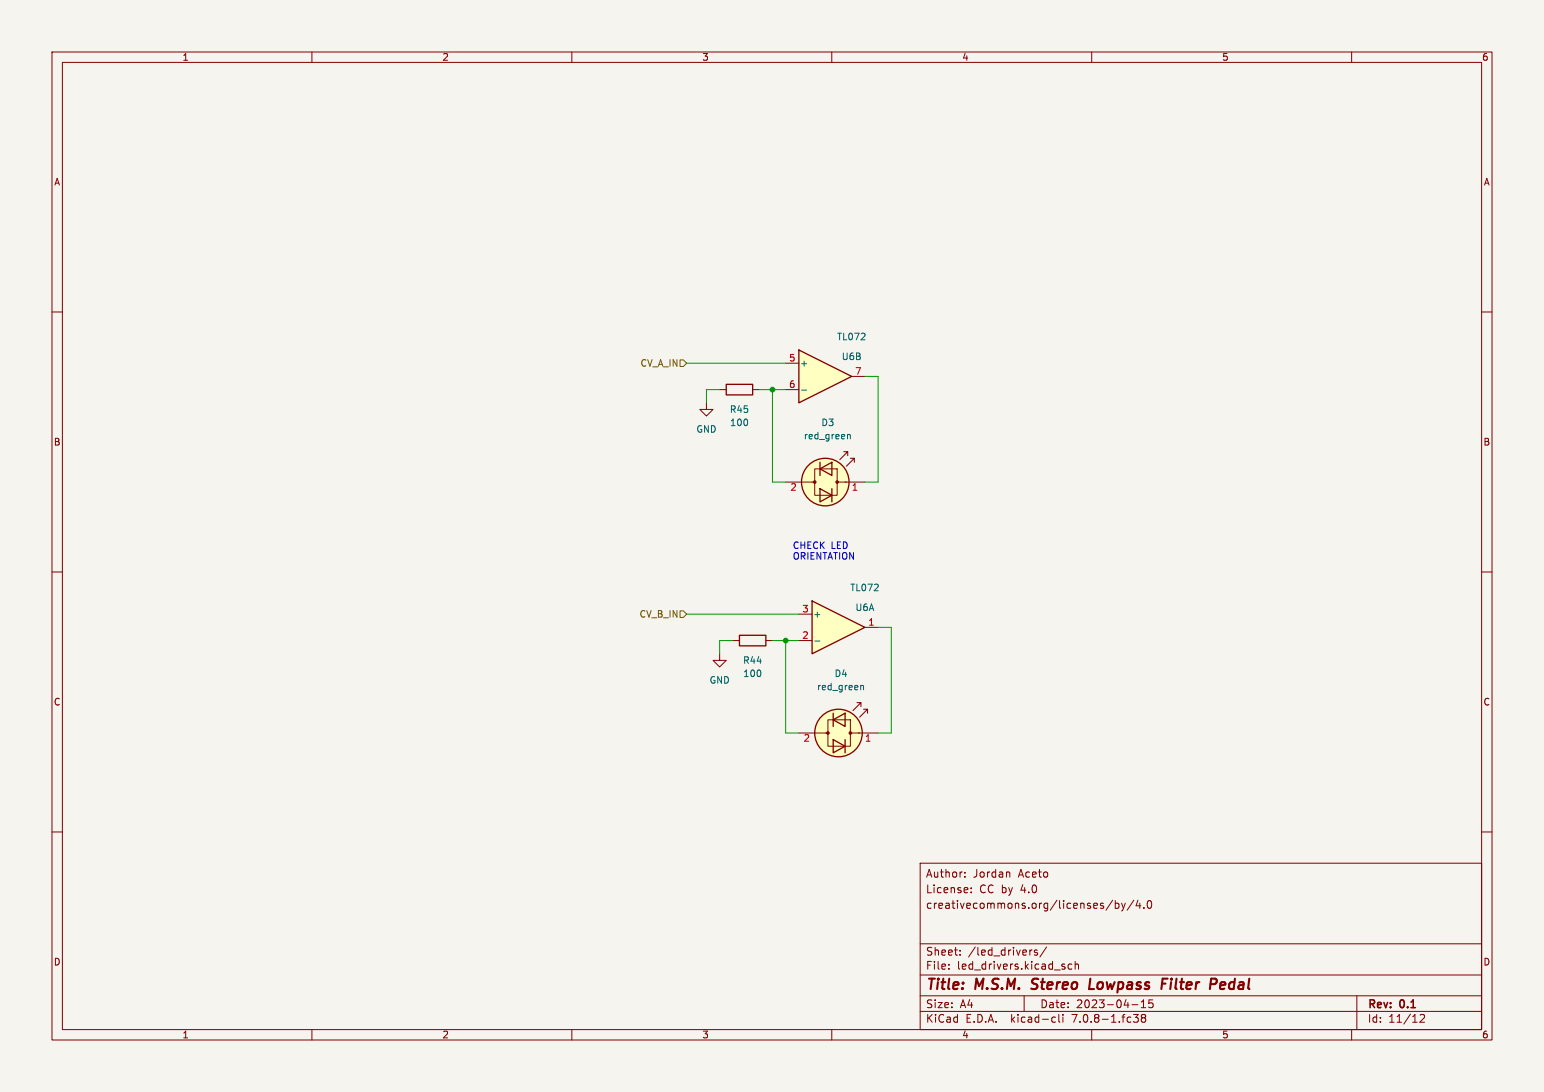
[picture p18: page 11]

creativecommons.org/licenses/by/4.0

Id: 11/12 Title: M.S.M. Stereo Lowpass Filter Pedal File: led_drivers.kicad_sch Sheet: /led_drivers/

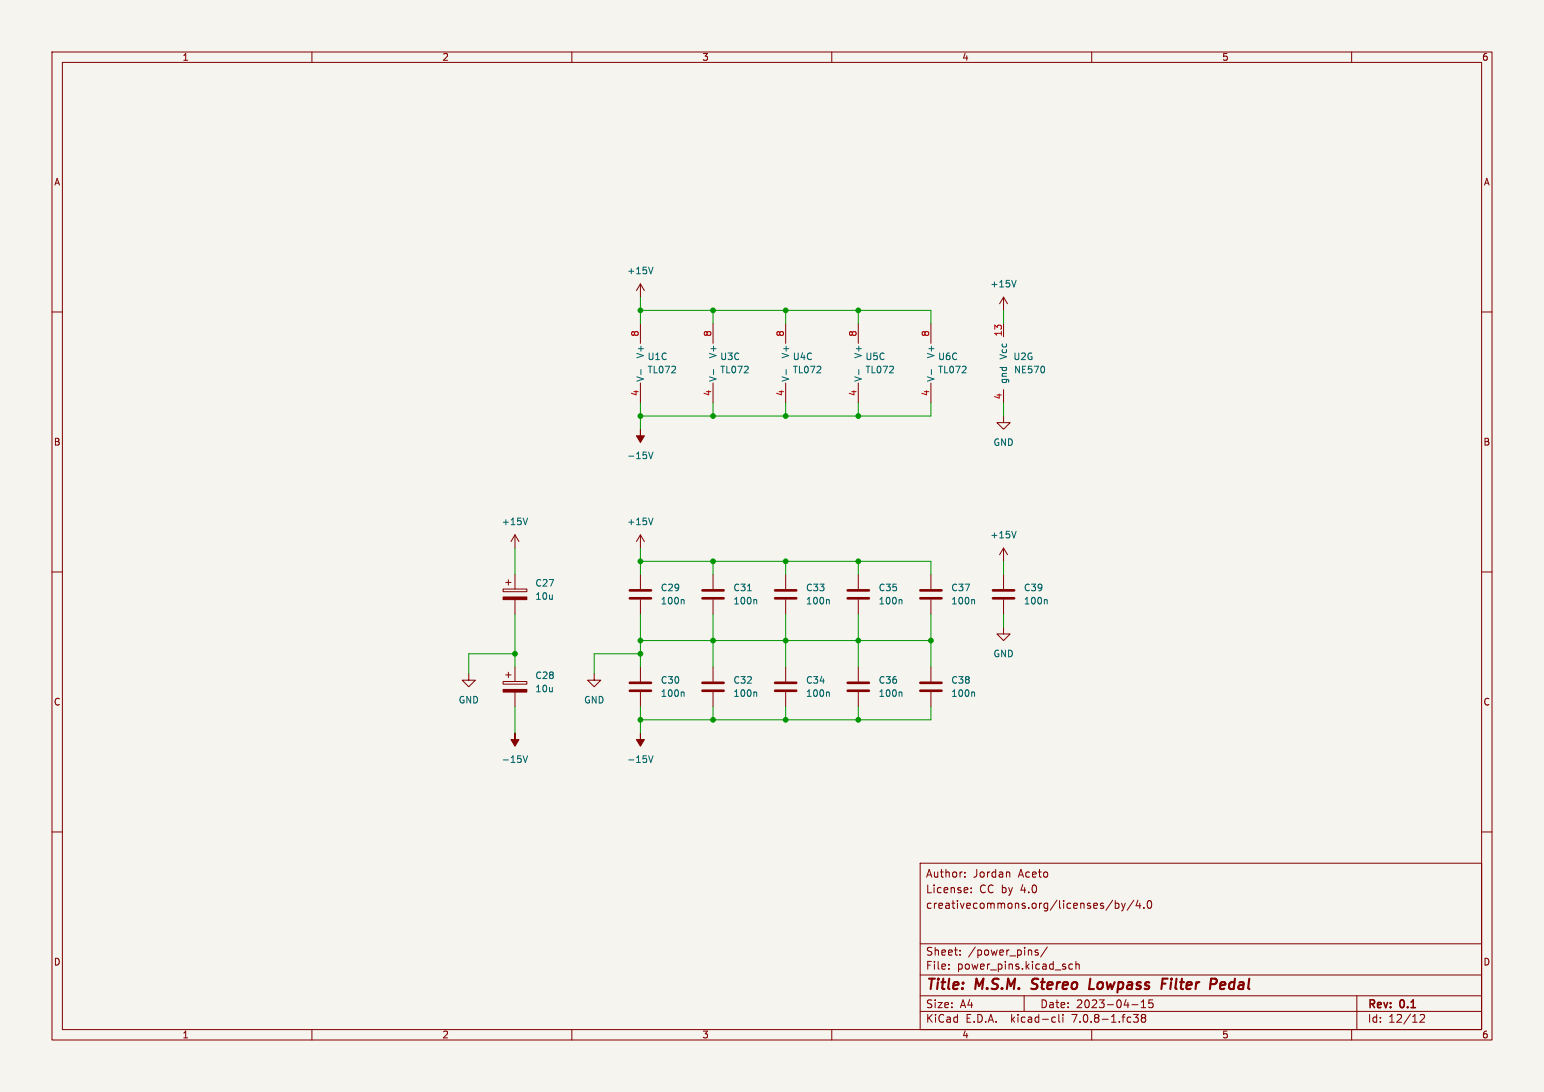
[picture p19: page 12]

creativecommons.org/licenses/by/4.0

Id: 12/12 Title: M.S.M. Stereo Lowpass Filter Pedal File: power_pins.kicad_sch Sheet: /power_pins/

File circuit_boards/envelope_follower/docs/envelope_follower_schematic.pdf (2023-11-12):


Id: 1/5 Title: M.S.M. Stereo Lowpass Filter Pedal File: envelope_follower.kicad_sch Sheet: / creativecommons.org/licenses/by/4.0


Id: 2/5 Title: M.S.M. Stereo Lowpass Filter Pedal File: fwr.kicad_sch Sheet: /fwr/ creativecommons.org/licenses/by/4.0


creativecommons.org/licenses/by/4.0

Id: 3/5 Title: M.S.M. Stereo Lowpass Filter Pedal File: lpf.kicad_sch Sheet: /lpf/


Id: 4/5 Title: M.S.M. Stereo Lowpass Filter Pedal File: attenuverters.kicad_sch Sheet: /attenuverters/ creativecommons.org/licenses/by/4.0


creativecommons.org/licenses/by/4.0

Id: 5/5 Title: M.S.M. Stereo Lowpass Filter Pedal File: power_supply.kicad_sch Sheet: /power_supply/

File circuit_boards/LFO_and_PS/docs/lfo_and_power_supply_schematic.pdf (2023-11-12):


LFO_B_FINAL Power headers for supplying

DC power to the other boards

Id: 1/3 Title: M.S.M. Stereo Lowpass Filter Pedal File: lfo_and_power_supply.kicad_sch Sheet: / creativecommons.org/licenses/by/4.0


1 ~{CS} 2 SCK 3 SDI 4 ~{LDAC} 5 VB 6 Vss 7 VA 8 U3 MCP4822 +3.3V GND

1 ~{CS} 2 SCK 3 SDI 4 ~{LDAC} 5 VB 6 Vss 7 VA 8 GND GND GND

Depth A pot has a push-pull switch and is mounted offboard. The switch sets LFO A to a

creativecommons.org/licenses/by/4.0

Id: 3/3 Title: M.S.M. Stereo Lowpass Filter Pedal File: digital_lfo.kicad_sch Sheet: /digital_lfo/


creativecommons.org/licenses/by/4.0

Id: 8/3 Title: M.S.M. Stereo Lowpass Filter Pedal File: power_supply.kicad_sch Sheet: /power_supply/

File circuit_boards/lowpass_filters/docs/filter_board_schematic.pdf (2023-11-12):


Id: 1/8 Title: M.S.M. Stereo Lowpass Filter Pedal File: filter_board.kicad_sch Sheet: / creativecommons.org/licenses/by/4.0


creativecommons.org/licenses/by/4.0

Id: 2/8 Title: M.S.M. Stereo Lowpass Filter Pedal File: lowpass_filter.kicad_sch Sheet: /lowpass_filter_A/


the feedback VCA accomplishes
loss of bass when the resonance
is turned up.

the dry signal can be changed or

creativecommons.org/licenses/by/4.0

Id: 3/8 Title: M.S.M. Stereo Lowpass Filter Pedal File: feedback_VCA.kicad_sch Sheet: /lowpass_filter_A/feedback_VCA/


creativecommons.org/licenses/by/4.0

Id: 4/8 Title: M.S.M. Stereo Lowpass Filter Pedal File: lowpass_filter.kicad_sch Sheet: /lowpass_filter_B/


the feedback VCA accomplishes
loss of bass when the resonance
is turned up.

the dry signal can be changed or

creativecommons.org/licenses/by/4.0

Id: 5/8 Title: M.S.M. Stereo Lowpass Filter Pedal File: feedback_VCA.kicad_sch Sheet: /lowpass_filter_B/feedback_VCA/


creativecommons.org/licenses/by/4.0

Id: 6/8 Title: M.S.M. Stereo Lowpass Filter Pedal File: wet_dry_mixers.kicad_sch Sheet: /wet_dry_mixers/


the feel of the
feedback pots if desired

creativecommons.org/licenses/by/4.0

Id: 7/8 Title: M.S.M. Stereo Lowpass Filter Pedal File: cv_generators.kicad_sch Sheet: /cv_generators/


creativecommons.org/licenses/by/4.0

Id: 8/8 Title: M.S.M. Stereo Lowpass Filter Pedal File: power_supply.kicad_sch Sheet: /power_supply/

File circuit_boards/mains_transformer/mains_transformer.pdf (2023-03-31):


The mains wiring and stepdown
transformer are connected with
point-to-point wiring, there
is no circuit board for these
components.

Molex MiniFit Jr connector
is attached to the transformer
with appropriate crimped
female pins.

This connector then mates with
the matching connector on the
power supply PCB.

Current drawn from the wall:
150mA @ 120VAC

Note that the wire colors on
the actual transformers are
sometimes different from the
factory.

Verify the transformer windings
before applying power.

License: CC by 4.0 Author: Jordan Aceto

File: mains_transformer.kicad_sch Sheet: / creativecommons.org/licenses/by/4.0

Id: 1/1 Title: M.S.M Stereo Lowpass Filter Mains Transformer

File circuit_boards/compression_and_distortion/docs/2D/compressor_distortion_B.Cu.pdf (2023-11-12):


File: compressor_distortion.kicad_pcb Sheet: creativecommons.org/licenses/by/4.0

Id: 1/1 Title: MSM Stereo VCF compressor and distortion board

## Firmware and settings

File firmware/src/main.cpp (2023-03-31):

#include "BSP_system_init.hpp"
#include "BSP_TIM2.hpp"
#include "LFO.hpp"
#include "lookup_tables.hpp"
#include "MCP4822.hpp"
#include "ui_controls.hpp"

/* the two independent LFO objects */
LFO lfo_A(BSP::tim2::FREQUENCY_Hz);
LFO lfo_B(BSP::tim2::FREQUENCY_Hz);

/* the user interface components, pots and switches */
UI ui{};

/**
 * @brief read the LFO rate controls and update the frequency for LFO A and B
 */
void update_lfo_frequency();

/**
 * @brief Get the shape to be used for LFO A based on the front panel toggle switch
 *
 * LFO A can be one of TRIANGLE, SQUARE, or RANDOM shapes depending on the position
 * of the front panel switch.
 *
 * LFO B is always set to TRIANGLE mode.
 *
 * @return LFO::Shape_t the shape to use for LFO A
 */
LFO::Shape_t get_lfo_A_shape();

/**
 * @brief calculate the final value to write to the DAC for output A
 *
 * When the sweep mode is INDEPENDENT or SYNC_TO_A, this is the value of LFO A
 * scaled by the depth A control
 *
 * When the sweep mode is ADD, this is the value of value of LFO A
 * scaled by the depth A control plus the value of LFO B scaled by
 * the depth B control
 *
 * @return int the value to write to the DAC for output A
 */
int calc_lfo_A_val();

/**
 * @brief calculate the final value to write to the DAC for output B
 *
 * When the sweep mode is INDEPENDENT, this is the value of LFO B
 * scaled by the depth B control, or -(LFO B) if the invert B switch is on
 *
 * When the sweep mode is SYNC_TO_A, this is the value of LFO A scaled by the
 * depth B control, or -(LFO A) if the invert B switch is on
 *
 * When the sweep mode is ADD, this is the value of LFO A
 * scaled by the depth A control plus the value of LFO B scaled by
 * the depth B control, or (LFO A) - (LFO B) if the invert B switch is on
 *
 * @return int
 */
int calc_lfo_B_val();

/**
 * @brief write the values of LFO A and B to the SPI DAC
 */
void write_to_dacs();

int main(void)
{
    BSP::system_init::init();

    while (1)
    {
        if (BSP::tim2::getTimeout())
        {
            lfo_A.tick();
            lfo_B.tick();

            update_lfo_frequency();
            write_to_dacs();
        }
    }

    // never reached
    return 0;
}

void update_lfo_frequency()
{
    int freq_lut_idx_ui10 = ui.get_control_signal_val(UI::LFO_A_FREQ);

    int lfo_A_freq = Lookup_Tables::EXPO_MAPPING_LUT_mHz[freq_lut_idx_ui10];

    if (ui.get_lfo_a_mode() == UI::lfo_a_mode::FAST)
    {
        // make it faster
        lfo_A_freq *= 20;
    }

    lfo_A.setInput(LFO::FREQ_mHz, lfo_A_freq);

    freq_lut_idx_ui10 = ui.get_control_signal_val(UI::LFO_B_FREQ);
    lfo_B.setInput(LFO::FREQ_mHz, Lookup_Tables::EXPO_MAPPING_LUT_mHz[freq_lut_idx_ui10]);
}

LFO::Shape_t get_lfo_A_shape()
{
    // the on-off-on toggle switch is read as an analog signal
    int wave_select_switch_val = ui.get_control_signal_val(UI::LFO_A_SHAPE);

    // the values are a result of the resistors used on the physical board, we
    // just need to pick breakpoints that ensure that the desired shapes are
    // returned and we're not so close to a boundary that it chatters between
    // shapes
    if (wave_select_switch_val < 100)
    {
        return LFO::RANDOM;
    }
    else if (wave_select_switch_val < 50000)
    {
        return LFO::SQUARE;
    }
    else
    {
        return LFO::TRIANGLE;
    }
}

int calc_lfo_A_val()
{
    int retval;

    switch (ui.get_sweep_mode())
    {
    // in INDEPENDENT and SYNC_TO_A modes just take the val of LFO A
    case UI::sweep_mode::INDEPENDENT:
    case UI::sweep_mode::SYNC_TO_A:
    {
        retval = ui.scale_bipolar_signal(
            lfo_A.getOutput(get_lfo_A_shape()),
            ui.get_control_signal_val(UI::LFO_A_LEVEL));
        break;
    }
    // in ADD mode, take (LFO A) + (LFO B)
    case UI::sweep_mode::ADD:
    {
        auto lfo_A_contrib = ui.scale_bipolar_signal(
            lfo_A.getOutput(get_lfo_A_shape()),
            ui.get_control_signal_val(UI::LFO_A_LEVEL));

        auto lfo_B_contrib = ui.scale_bipolar_signal(
            lfo_B.getOutput(LFO::TRIANGLE),
            ui.get_control_signal_val(UI::LFO_B_LEVEL));

        retval = lfo_A_contrib + lfo_B_contrib;
        break;
    }
    }

    return ui.condition_bipolar_signal_for_DAC(retval);
}

int calc_lfo_B_val()
{
    const auto lfo_B_mode = ui.get_lfo_b_mode();

    int retval;

    switch (ui.get_sweep_mode())
    {
    // in INDEPENDENT mode just take the val of LFO B, optionally inverted
    case UI::sweep_mode::INDEPENDENT:
    {
        retval = ui.scale_bipolar_signal(
            lfo_B.getOutput(LFO::TRIANGLE),
            ui.get_control_signal_val(UI::LFO_B_LEVEL));

        if (lfo_B_mode == UI::lfo_b_mode::INVERT)
        {
            retval = -retval;
        }
        break;
    }
    // in SYNC_TO_A modes just take the val of LFO A, optionally inverted
    case UI::sweep_mode::SYNC_TO_A:
    {
        retval = ui.scale_bipolar_signal(
            lfo_A.getOutput(get_lfo_A_shape()),
            ui.get_control_signal_val(UI::LFO_B_LEVEL));

        if (lfo_B_mode == UI::lfo_b_mode::INVERT)
        {
            retval = -retval;
        }
        break;
    }
    // in ADD mode, take (LFO A) + (LFO B), with LFO B optionally inverted
    case UI::sweep_mode::ADD:
    {
        auto lfo_A_contrib = ui.scale_bipolar_signal(
            lfo_A.getOutput(get_lfo_A_shape()),
            ui.get_control_signal_val(UI::LFO_A_LEVEL));

        auto lfo_B_contrib = ui.scale_bipolar_signal(
            lfo_B.getOutput(LFO::TRIANGLE),
            ui.get_control_signal_val(UI::LFO_B_LEVEL));

        if (ui.get_lfo_b_mode() == UI::lfo_b_mode::INVERT)
        {
            lfo_B_contrib = -lfo_B_contrib;
        }

        retval = lfo_A_contrib + lfo_B_contrib;
        break;
    }
    }

    return ui.condition_bipolar_signal_for_DAC(retval);
}

void write_to_dacs()
{
    MCP4822::write(calc_lfo_A_val(), MCP4822::Channel::A);
    MCP4822::write(calc_lfo_B_val(), MCP4822::Channel::B);
}

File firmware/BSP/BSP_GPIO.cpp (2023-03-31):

#include "BSP_GPIO.hpp"
#include "stm32l031xx.h"

namespace BSP::gpio
{
    static void enable_GPIO_clock_control(void);

    static void set_switch_pins_to_input_pullup(void);

    static void setup_spi_pins(void);

    void init()
    {
        enable_GPIO_clock_control();
        set_switch_pins_to_input_pullup();
        setup_spi_pins();
    }

    bool getPinState(pin_t pin)
    {
        bool retval = 0;
        switch (pin)
        {
        case pin_t::PA9:
            retval = (GPIOA->IDR >> 9u) & 1u;
            break;
        case pin_t::PA10:
            retval = (GPIOA->IDR >> 10u) & 1u;
            break;
        case pin_t::PC14:
            retval = (GPIOC->IDR >> 14u) & 1u;
            break;
        case pin_t::PC15:
            retval = (GPIOC->IDR >> 15u) & 1u;
            break;
        }

        return retval;
    }

    void enable_GPIO_clock_control(void)
    {
        RCC->IOPENR |= RCC_IOPENR_IOPAEN | RCC_IOPENR_GPIOBEN | RCC_IOPENR_GPIOCEN;
    }

    void set_switch_pins_to_input_pullup(void)
    {
        // set pins to inputs
        GPIOA->MODER &= ~GPIO_MODER_MODE9_Msk;
        GPIOA->MODER &= ~GPIO_MODER_MODE10_Msk;
        GPIOC->MODER &= ~GPIO_MODER_MODE14_Msk;
        GPIOC->MODER &= ~GPIO_MODER_MODE15_Msk;

        // enable pullups
        GPIOA->PUPDR |= GPIO_PUPDR_PUPD9_0;
        GPIOA->PUPDR |= GPIO_PUPDR_PUPD10_0;
        GPIOC->PUPDR |= GPIO_PUPDR_PUPD14_0;
        GPIOC->PUPDR |= GPIO_PUPDR_PUPD15_0;
    }

    void setup_spi_pins(void)
    {
        // set spi SCK and MOSI to special function
        GPIOA->MODER &= ~GPIO_MODER_MODE5_Msk;
        GPIOA->MODER &= ~GPIO_MODER_MODE7_Msk;
        GPIOA->MODER |= GPIO_MODER_MODE5_1;
        GPIOA->MODER |= GPIO_MODER_MODE7_1;

        // set spi CS pin to output
        GPIOA->MODER &= ~GPIO_MODER_MODE6_Msk;
        GPIOA->MODER |= GPIO_MODER_MODE6_0;

        // write the CS pin high
        GPIOA->BSRR = GPIO_BSRR_BS_6;
    }
}

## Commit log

2022-05-24 Initial filter board layout
    [cv_generators.kicad_sch, feedback_VCA.kicad_sch, filter_board.kicad_pcb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]
2022-05-24 Filter board rev 0 and outputs
    [cv_generators.kicad_sch, feedback_VCA.kicad_sch, filter_board.kicad_pcb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]
2022-05-26 Env follower rev 0 and outputs
    [attenuverters.kicad_sch, envelope_follower.kicad_pcb, envelope_follower.kicad_sch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]
2022-05-26 Comp dist rev 0 and outputs
    [compressor.kicad_sch, compressor_distortion.kicad_pcb, compressor_distortion.kicad_sch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]
2022-05-26 Fix BOM name typo
2022-05-27 Fix filter board silkscreen error
    [filter_board.kicad_pcb]
2022-06-07 Progress on LFO/PS board
    [LFO_A.kicad_sch, LFO_B.kicad_sch, LFO_CV_processors.kicad_sch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]
2022-06-16 Tweak some filter board values
    [cv_generators.kicad_sch, feedback_VCA.kicad_sch, filter_board.kicad_pcb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]
2023-03-31 Update PCB files, fix VCF mix polarity
    [attenuverters.kicad_sch, compressor.kicad_sch, compressor_distortion.kicad_pcb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]
2023-03-31 Add pcb documentation files
    [compressor_distortion-B_Cu.dxf, compressor_distortion-B_Mask.dxf, compressor_distortion-B_Silkscreen.dxf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]
2023-03-31 Add individual PCB READMEs with images
2023-03-31 Fix switch orientations, change the way LFO waveshapes are handled
    [main.cpp, ui_controls.cpp]
2023-04-15 Fix a/b swap error and dim LED error
    [compressor.kicad_sch, compressor_distortion-B_Cu.dxf, compressor_distortion-B_Mask.dxf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]
2023-04-15 Update silkscreen to match rev and date
    [compressor_distortion-B_Silkscreen.dxf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]
2023-04-15 Choose values for R7 and R9
    [lfo_and_power_supply--NPTH_map.gbr, lfo_and_power_supply--PTH_map.gbr, lfo_and_power_supply-B_Cu.gbl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]
2023-11-12 Update to KiCad 7, tweak some values for gain staging, EF attack
    [attenuverters.kicad_sch, compressor.kicad_sch, compressor_distortion-B_Cu.dxf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]
